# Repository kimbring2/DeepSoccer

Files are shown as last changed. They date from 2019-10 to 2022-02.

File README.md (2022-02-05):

# 1. Introduction
The purpose of this project is to make a soccer robot. For that, Robot Operation System (ROS), Deep Learning, 3D printer and Cad are used together. 

Due to the characteristic of Deep Learning, a large amount of training data is required. Thus, virtual simulation tool of ROS called Gazebo is additionally used. The project uses the one of famous Deep Reinforcement Learning algorithm which uses a human expert data for improving performance.

In order to use the robot algorithm trained in the virtual simulation in the real world, I use a CycleGAN for generating view of simulation world from view of real world. 

Finally, hardware information of robot also will be shared as 3D CAD format to allow other researchers, makers can use this project for their own purpose.

More detailed instruction can be found at my [blog post of DeepSoccer](https://kimbring2.github.io/2020/10/08/deepsoccer.html)

# 2. Prerequisite
This project started from originally [Jetbot](https://www.amazon.com/Waveshare-JetBot-AI-Kit-Accessories/dp/B07V8JL4TF/?th=1). Therefore, the hardware and software are advanced form of Jetbot. It is highly recommended that you first try to run original Jetbot before trying DeepSoccer.

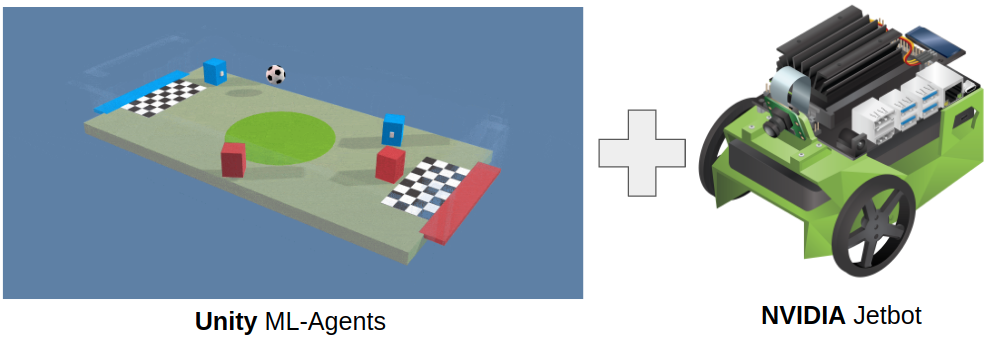
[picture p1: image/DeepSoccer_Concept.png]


# 3. Robot design
I remodel hardware of Jetbot because it is not suitable for soccer. As you know easily, soccer robot needd a kicking and holding part. The Jetbot soccer version can hold a soccer ball and kick it. The wheel part is changed to omniwheel type for moving more freely.

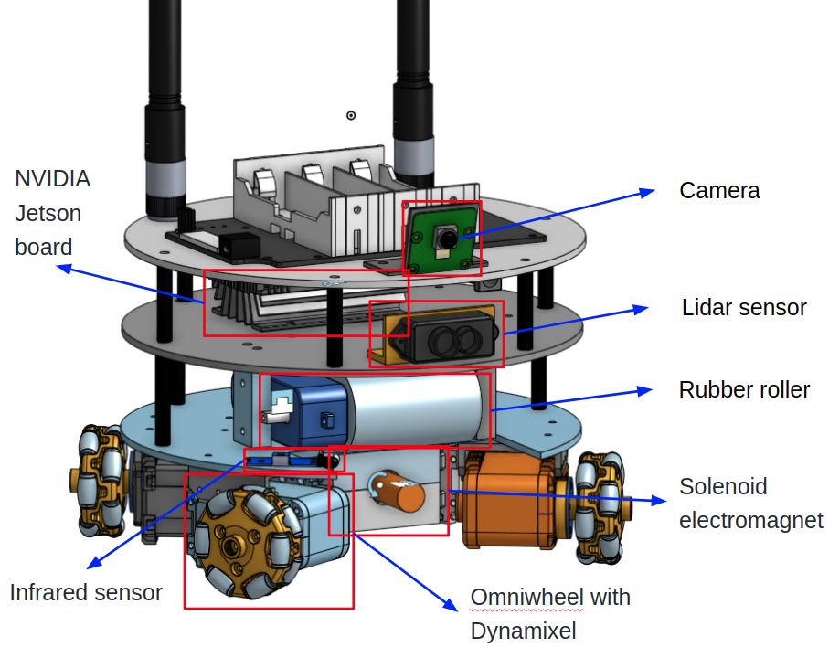
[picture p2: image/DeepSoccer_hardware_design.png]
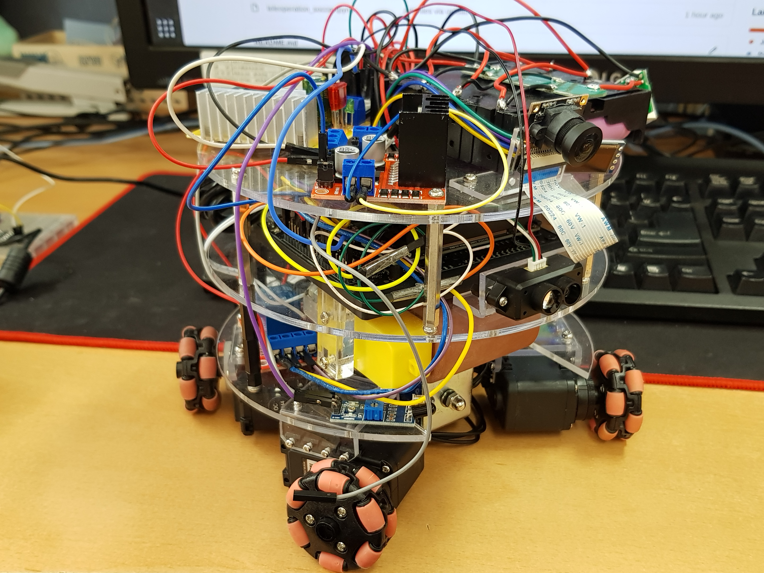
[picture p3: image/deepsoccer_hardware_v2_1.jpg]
 
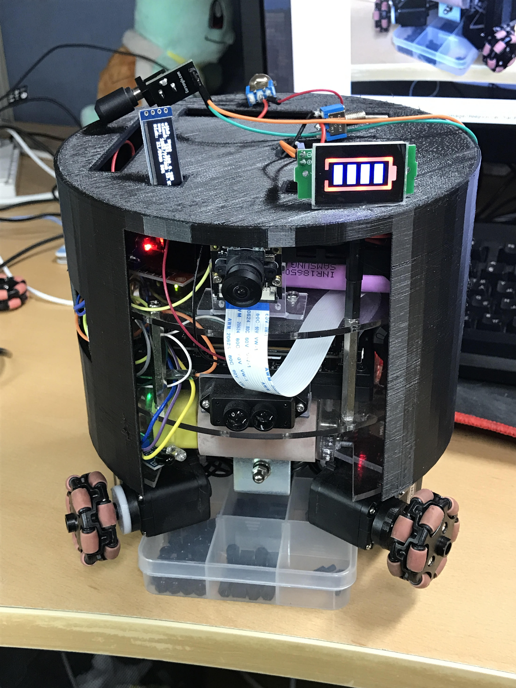
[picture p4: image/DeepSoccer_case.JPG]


You can see detailed information about hardware design at https://kimbring2.github.io/2020/10/08/deepsoccer.html#design_deepsoccer.

# 5. Simulation
## 1. Software Dependency
- ROS Melodic, Gazebo 9
- ROS openai_ros package
- Gazebo only provides Python 2.7(From ROS Noetic at Ubuntu 20.04, Python3 can be used)
- Tensorflow 2.1.0
- requests 
- pynput
- opencv-python

## 2. Network Architecture
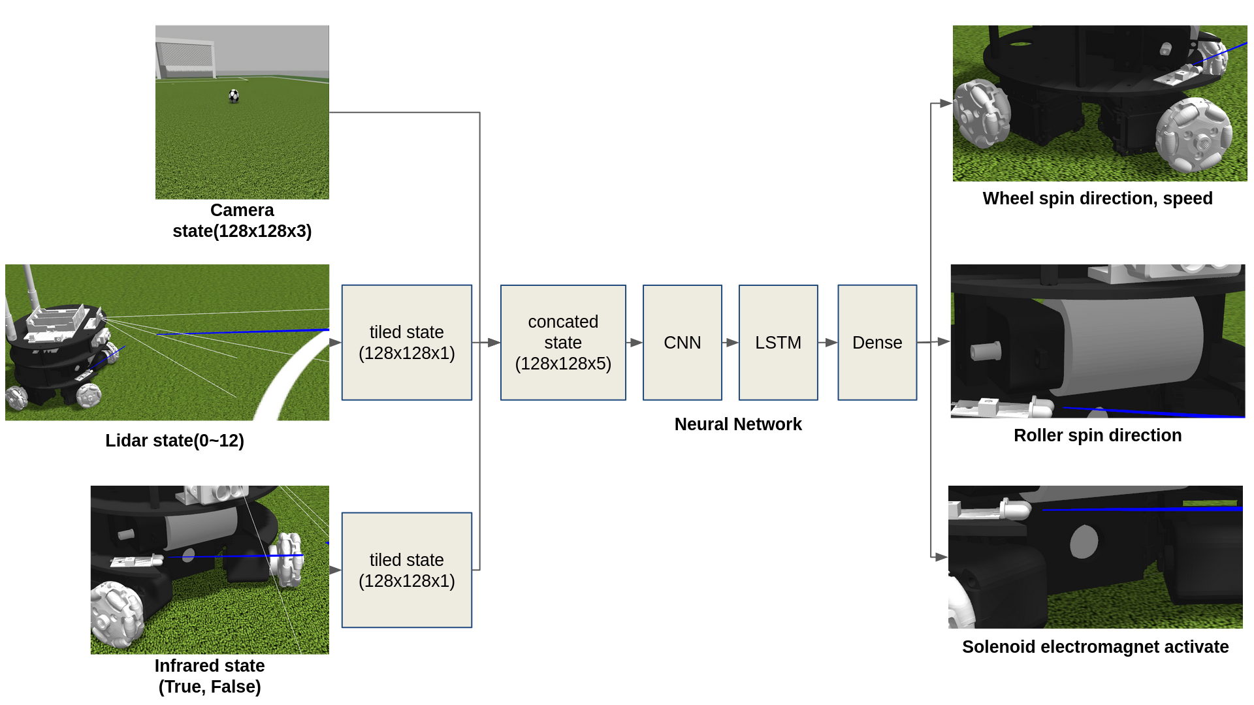
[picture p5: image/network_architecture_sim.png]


## 3. Usage
### ROS package
Please put [deepsoccer_pc](https://github.com/kimbring2/DeepSoccer/tree/master/deepsoccer_pc), [openai_ros](https://github.com/kimbring2/DeepSoccer/tree/master/openai_ros), [openai_ros](https://github.com/kimbring2/DeepSoccer/tree/master/openai_ros), [solenoid_electromagnet_joint_spring_plugin](https://github.com/kimbring2/DeepSoccer/tree/master/solenoid_electromagnet_joint_spring_plugin), [my_deepsoccer_training](https://github.com/kimbring2/DeepSoccer/tree/master/my_deepsoccer_training) folder to your ROS workspace. For example, my path '/home/kimbring2/catkin_ws/src'.

Then, try to run below command to build all ROS package what we put.
```
$ cd ~/catkin_ws/src/
$ git clone https://github.com/kimbring2/DeepSoccer.git
$ cd ..
$ catkin_make
```

If there are no error message, move to next.

### Set model file for soccer field
Copy [deepsoccer_gazebo](https://github.com/kimbring2/DeepSoccer/tree/master/deepsoccer_pc/deepsoccer_gazebo) folder to '/home/[Your User Name]/.gazebo/models' for soccer field rendering.

### Training network using Supervised Learning&Reinforcement Learning
After setting everything mentioned above, download the [human expert data](https://drive.google.com/drive/folders/1QmYI_FL5cym3LTvm8hlLfZ1Bo50bUyfc?usp=sharing) from Google Drive. I collected that data manually. 

After that, extract it to your workspace folder. You need to set a workspace_path in [yaml file](https://github.com/kimbring2/DeepSoccer/blob/master/my_deepsoccer_training/config/deepsoccer_params.yaml).

After preparing the human expert data and config file, run below command. It will start a [tutorial file](https://github.com/kimbring2/DeepSoccer/blob/master/my_deepsoccer_training/src/gym_tutorial.py) of DeepSoccer as format of OpenAI Gym environment. 

```
$ source devel/setup.bash
$ roslaunch my_deepsoccer_training start_tutorial.launch
```

Trained model, Tensorboard log are saved under 'src/train/' folder seperately. Try to check the loss is decreased under 0.3 point. 

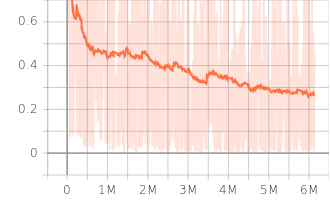
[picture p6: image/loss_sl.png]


If you set the sl_training config to False, pretrained_model to file name of trained model, it will start the Reinforcmenet Learning phase using trained model.

DeepSoccer Supervised Learning demo (https://youtube.com/watch?v=64ENY3P8U88 "DeepSoccer- Click to Watch!")
<strong>Click to Watch!</strong>

### Collection human expert data
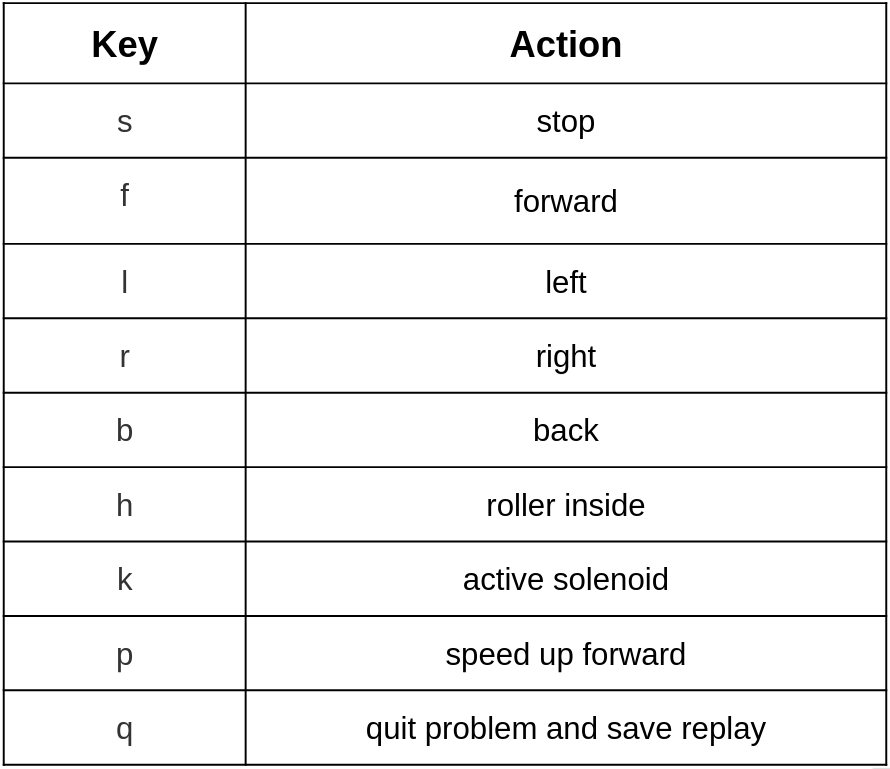
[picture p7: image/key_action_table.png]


You can also collect the human expert dataset using 'roslaunch my_deepsoccer_training start_dataset.launch' command. After Gazebo screen is poped up, you can control robot using 8 command.

The name of the replay file and the path to be saved can be set in the [config file](https://github.com/kimbring2/DeepSoccer/blob/master/my_deepsoccer_training/config/deepsoccer_params.yaml).

## 4. Troubleshooting 
### 1) RLException Error
If you get a 'RLException' error message, use 'source devel/setup.bash' command and try again.

### 2) Could not find the GUI, install the 'joint_state_publisher_gui' package Error
If you get that error when try to run 'roslaunch jetbot_description jetbot_rviz.launch' command, try to install related package using below command at your terminal.

```
$ sudo apt install ros-melodic-joint-state-publisher-gui
```

### 3) Could not load controller Error
If you get a 'Could not load controller' error message, try to install related package using below command at your terminal.

```
$ sudo apt-get install ros-melodic-ros-control ros-melodic-ros-controllers
```

### 4) RViz 'No transform from' error

If you get error message includes 'No transform from', try to install unicode ubuntu package and reboot.

```
$ sudo apt-get install unicode 
```

## 5. Docker 
You can also use a Docker image for this repo using below command. Afte that, you can connect to created container by VNC(http://127.0.0.1:6080/#/).

```
$ docker run -it --rm -p 6080:80 --name=env_1 kimbring2/deepsoccer:latest
```

Because of low speed of Gazebo simulation in Docker image, you need to see Gazebo of it by using host PC. However, you shoud place ROS package to ' /root/catkin_ws/src' for rendering robot model. After that, get IP address of Docker image and connect to it by using below command.

```
$ export GAZEBO_MASTER_IP=$(docker inspect --format '{{ .NetworkSettings.IPAddress }}' env_1)
$ export GAZEBO_MASTER_URI=$GAZEBO_MASTER_IP:11345
$ gzclient --verbose
```

After connecting to the docker image with VNC, move to the catkin_ws folder. Then, you can start the simulation by executing the following command.

# 6. Relationship between simualtion and real part
The purpose of this project is to train Jetbot to play soccer based on simulation and then apply trained model to actual Jetbot. Therefore, I am currently updating the code and description of the current simulation robot and the actual robot to this repository together.

Each ROS package for simulation and real robot is placed separately in two folder.

1. ROS package for simulation robot: https://github.com/kimbring2/DeepSoccer/tree/master/deepsoccer_pc
2. ROS package for real robot: https://github.com/kimbring2/DeepSoccer/tree/master/deepsoccer_jetson
3. Simulation to Real to connect 1, 2 method: https://github.com/kimbring2/DeepSoccer/blob/master/sim2real

You can run each part separately. However, two part should be connected by sim2real method.

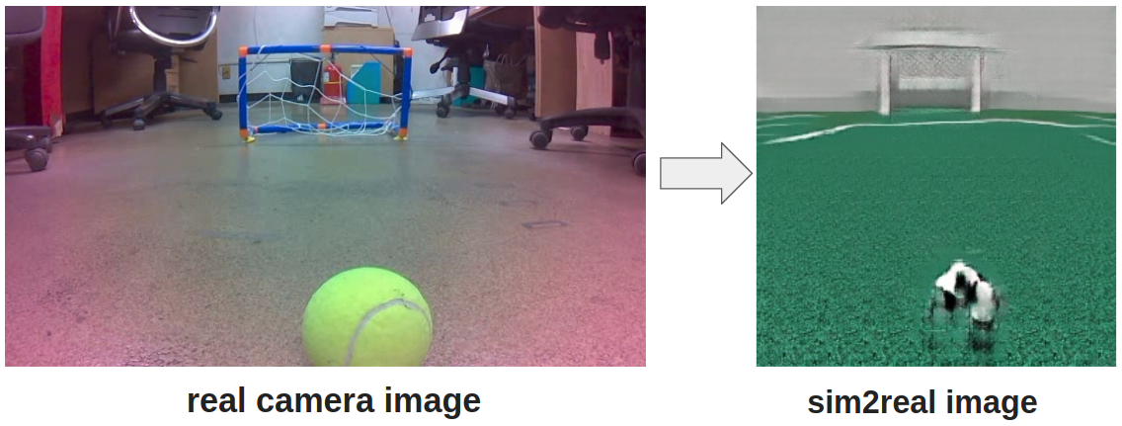
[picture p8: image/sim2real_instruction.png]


# 7. Reference
- Jetbot SDF file, ROS: [Jetbot SDF file, ROS](https://github.com/dusty-nv/jetbot_ros)
- Gazebo parameter setting: [Gazebo parameter](https://github.com/CentroEPiaggio/irobotcreate2ros)
- URDF file usage in Gazebo: [URDF file usage in Gazebo](http://gazebosim.org/tutorials/?tut=ros_urdf)
- Object detecion using cvlib: [Object detecion using cvlib](https://towardsdatascience.com/object-detection-with-less-than-10-lines-of-code-using-python-2d28eebc5b11)
- Soccer field, ball model: [Soccer field, ball model](https://github.com/RoboCup-MSL/MSL-Simulator)
- Reinforcement Learnig model: [Reinforcement Learnig model](https://medium.com/emergent-future/simple-reinforcement-learning-with-tensorflow-part-6-partial-observability-and-deep-recurrent-q-68463e9aeefc)
- Inference saved model: [Tensorrt](http://litaotju.github.io/2019/01/24/Tensorflow-Tutorial-6,-Using-TensorRT-to-speedup-inference/)
- Onshape 3D model to URDF: [onshape-to-robot](https://github.com/rhoban/onshape-to-robot/)
- GPIO control for solenoid electromagnet : https://www.jetsonhacks.com/2019/06/07/jetson-nano-gpio/ ,https://github.com/NVIDIA/jetson-gpio
- Ball kicking mechanism: https://www.youtube.com/watch?v=fVGrYoqn-EU
- How to read LaserScan data(ROS python): https://www.theconstructsim.com/read-laserscan-data/
- Convert Video to Images (Frames) & Images (Frames) to Video using OpenCV (Python) : https://medium.com/@iKhushPatel/convert-video-to-images-images-to-video-using-opencv-python-db27a128a481
- Python Multithreading with pynput.keyboard.listener: https://stackoverflow.com/a/59520236/6152392
- How to use a Gazebo as type of OpenAI Gym: http://wiki.ros.org/openai_ros
- Solenoid joint spring plugin: https://github.com/aminsung/gazebo_joint_torsional_spring_plugin
- Custom control plugin for Gazebo: http://gazebosim.org/tutorials?tut=guided_i5&cat=
- Forgetful Expirience Replay for Reinforcement Learning from Demonstrations: https://github.com/cog-isa/forger
- Compiling ROS cv_bridge with Python3: https://cyaninfinite.com/ros-cv-bridge-with-python-3/
- Style Transfer for Sim2Real: https://github.com/cryu854/FastStyle
- CycleGAN for Sim2Real: https://www.tensorflow.org/tutorials/generative/cyclegan
- Image Segmentation for CycleGAN: https://www.kaggle.com/santhalnr/cityscapes-image-segmentation-pspnet
- Docker Gazebo: https://hub.docker.com/_/gazebo
- Docker image for ROS melodic: https://github.com/fbottarel/docker-ros-desktop-full

# 8. Citation
If you use DeepSoccer to conduct research, we ask that you cite the following paper as a reference:

```
@misc{kim2020deepsoccer,
  author = {Dohyeong, Kim},
  title = {DeepSoccer},
  year = {2020},
  publisher = {GitHub},
  journal = {GitHub repository},
  howpublished = {\url{https://github.com/kimbring2/DeepSoccer/}},
  commit = {9ccab28a7e2a9a14caa119a765f95e2c6d0b044e}
}
```

# 9. Acknowledgement
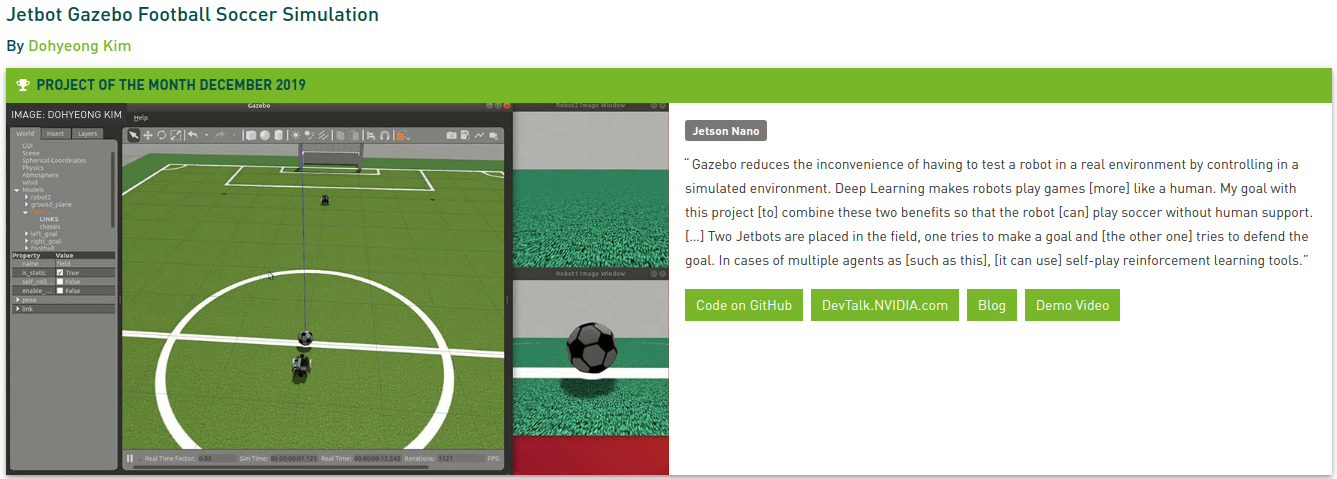
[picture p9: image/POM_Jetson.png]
 <strong>I receive a prize from NVIDIA for this project</strong>

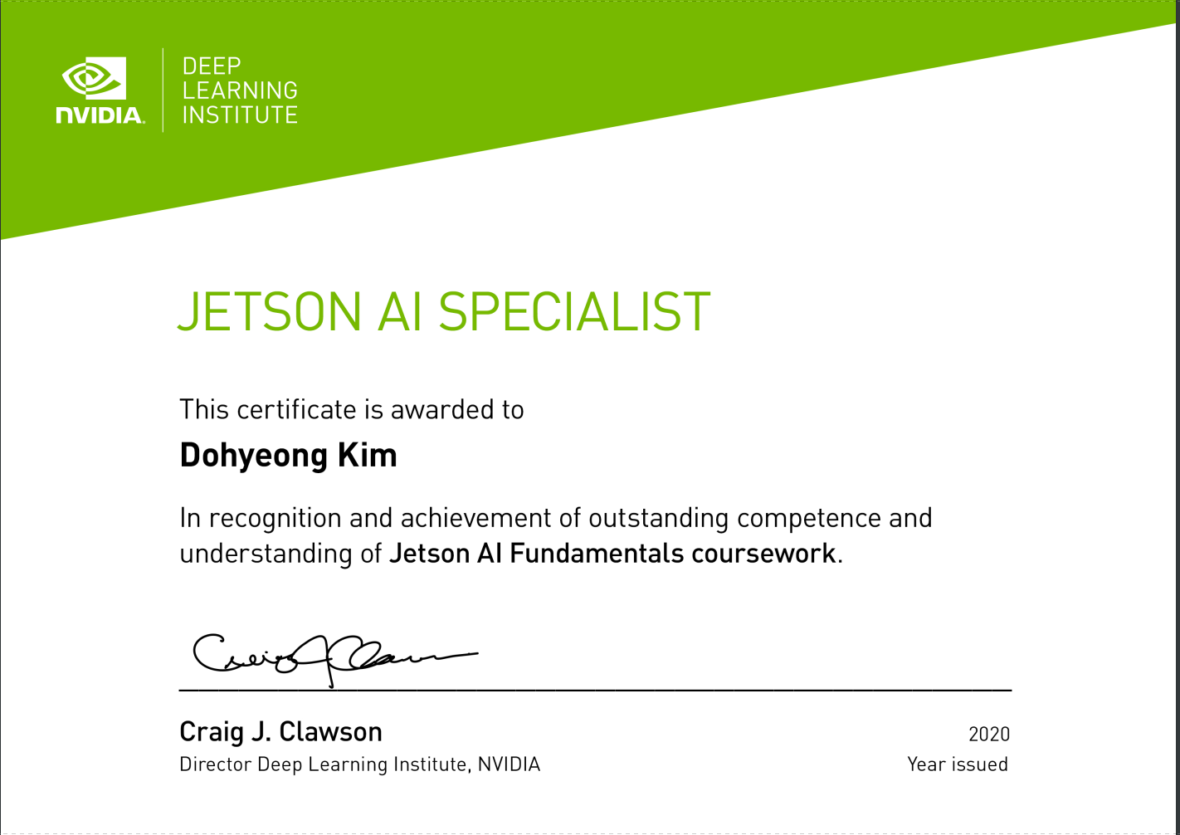
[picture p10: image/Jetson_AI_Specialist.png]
 <strong>I receive Jetson AI Specialist certification from NVIDIA by this project</strong>

# 10. License
Apache License 2.0

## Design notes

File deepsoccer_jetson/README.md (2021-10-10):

# 1. Software Dependency
- JetPack 4.4
- ROS Melodic
- Tensorflow 2.2.0
- Python2 for ROS acuator, sensor node
- Python3 for ROS main node

# 2. Prepare hardware
## Main Board
The main board used in DeepSoccer is Jetson Xavier NX which can run three Deep Learning model at the same time unlike Jetson Nano which can handle only one model one time. However, Jetson Xavier NX is little expensive compared to Jetson Nano. 

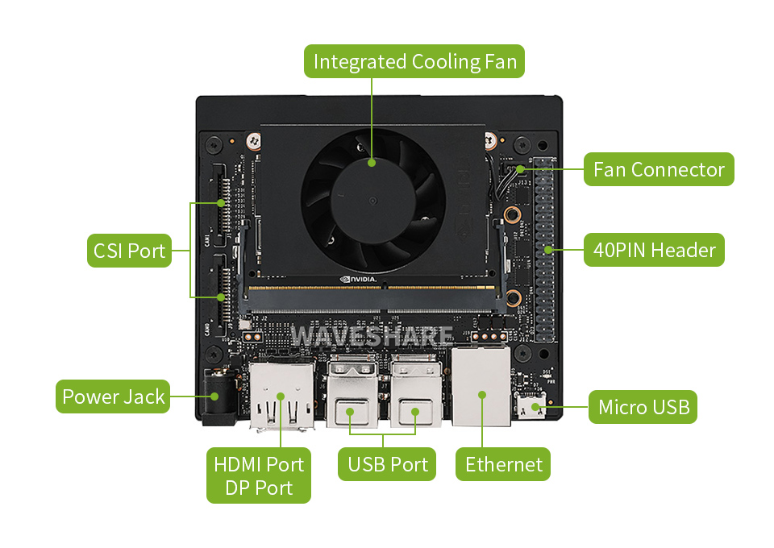
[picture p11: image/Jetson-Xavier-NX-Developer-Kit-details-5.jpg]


This board can run ROS, Python, and Tensorflow. Therefore, you can develop yout own application easily. It is also very convenient to use sensors and actuators as it supports almost all communication interfaces such as I2C, SPI, Digital input / output, CSI and USB.

1. [NVIDIA Jetson Xavier NX](https://www.amazon.com/NVIDIA-Jetson-Xavier-Developer-812674024318/dp/B086874Q5R)

Purchases can generally be made through Amazon. Unlike the Jetson Nano, which can be operated with three 18650 batteries, the Jetson Xavier NX requires four 18650 batteries to operate stably. 

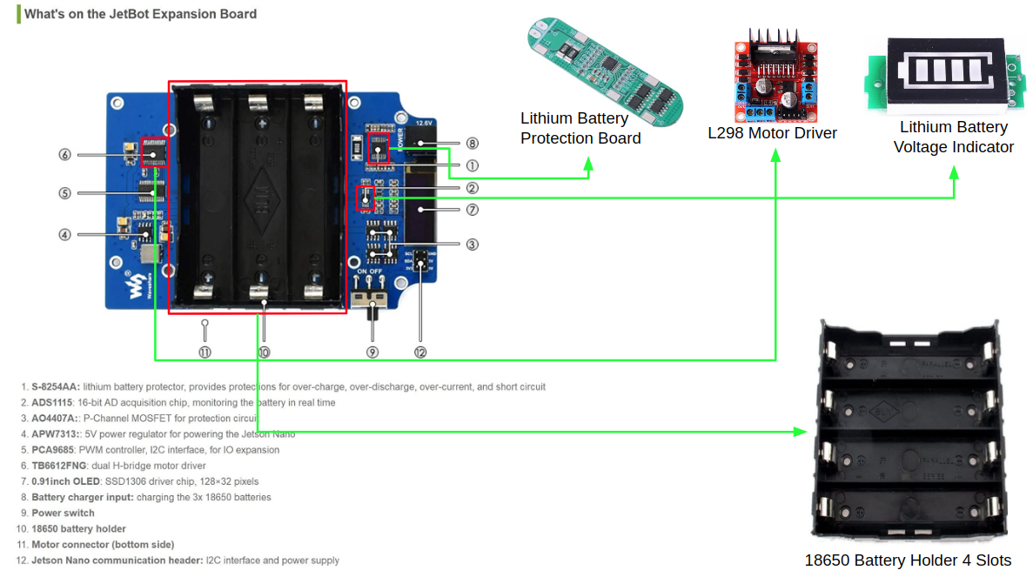
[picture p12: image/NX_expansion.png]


2. [18650 Battery Holder 4 Slots](https://www.amazon.com/abcGoodefg-Battery-Holder-Plastic-Storage/dp/B071XTGBH6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)
3. [Lithium Battery Protection Board](https://www.amazon.com/ZRM-Lithium-Protection-Overcharge-Electronic/dp/B07RGPSSQS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)
4. [Lithium Battery Voltage Indicator](https://www.amazon.com/1S-3-7V-Battery-Voltage-Tester/dp/B01N9M05DA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)
5. [L298 Motor Driver](https://www.amazon.com/HiLetgo-Controller-Stepper-H-Bridge-Mega2560/dp/B07BK1QL5T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)

## OLED
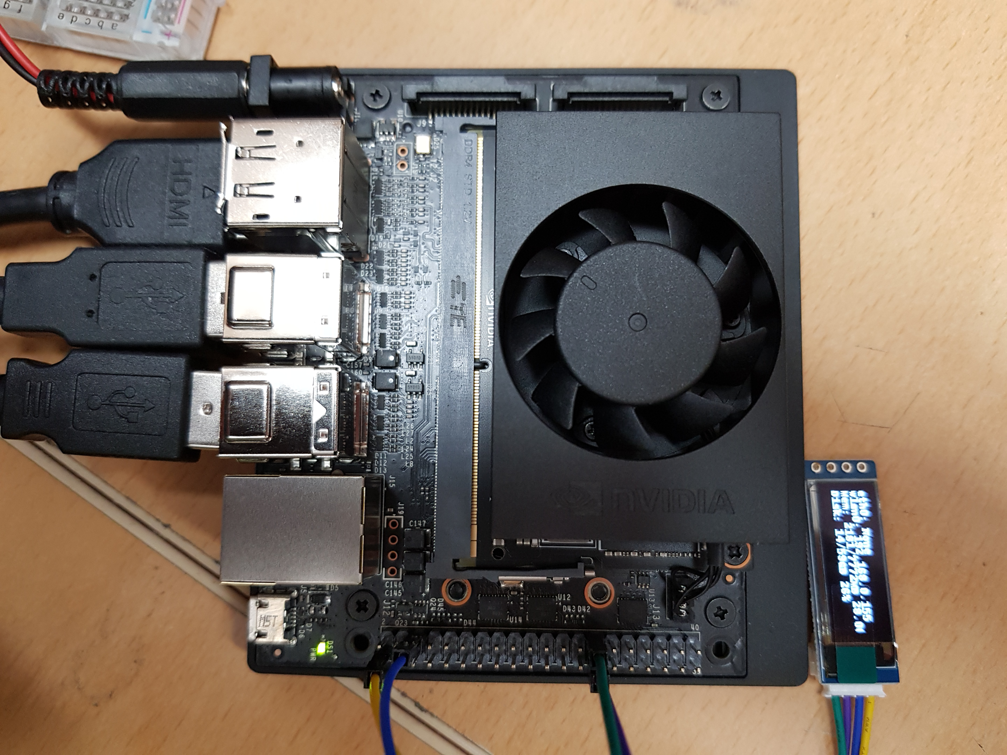
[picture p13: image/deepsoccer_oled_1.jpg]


DeepSoccer has OLED display like an original Jetbot to monitor IP Address, memory usage without monitor connection.

1. [Waveshare OLED module](https://www.waveshare.com/0.91inch-oled-module.htm)

Jetson Xavier NX is connected to OLED module by using VDC, GND and SCL, SDA of 0 Channel I2C.

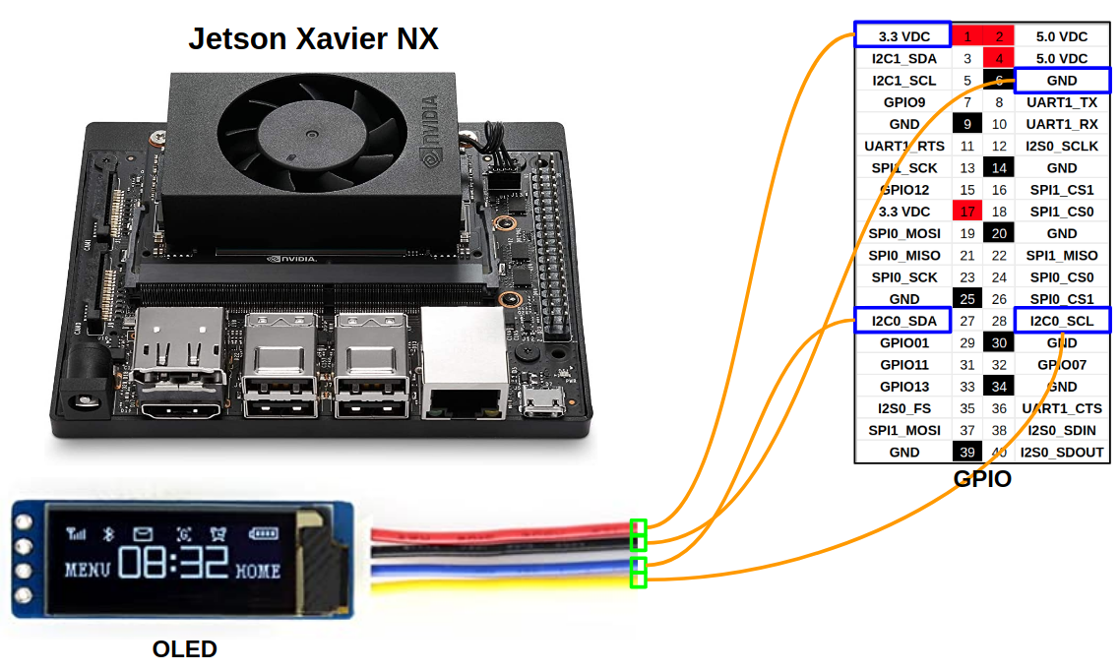
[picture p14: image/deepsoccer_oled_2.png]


After connecting the hardware, download the Jetbot package from https://github.com/NVIDIA-AI-IOT/jetbot to Jetson Xaiver NX and install it using setup.py file. In this package, execute a python file(https://github.com/NVIDIA-AI-IOT/jetbot/blob/master/jetbot/utils/create_stats_service.py) that displays the current information in OLED.

After that, try to register sevice to execute OLED file automatically when the board boot. First, move to /etc/systemd/system/ location of Ubuntu. Then, create a file named deepsoccer_stats.service with following contents.

```
[Unit]
Description=DeepSoccer stats display service
[Service]
Type=simple
User=kimbring2
ExecStart=/bin/sh -c "python3 /home/kimbring2/jetbot/jetbot/apps/stats.py"
Restart=always
[Install]
WantedBy=multi-user.target
```

Then, register the file as a service and start it as shown below.

```
$ systemctl daemon-reload
$ systemctl enable deepsoccer_stats
$ systemctl start deepsoccer_stats
```

The registered service can be confirmed with the following command.

```
sudo systemctl status deepsoccer_stats
```

## Wheel
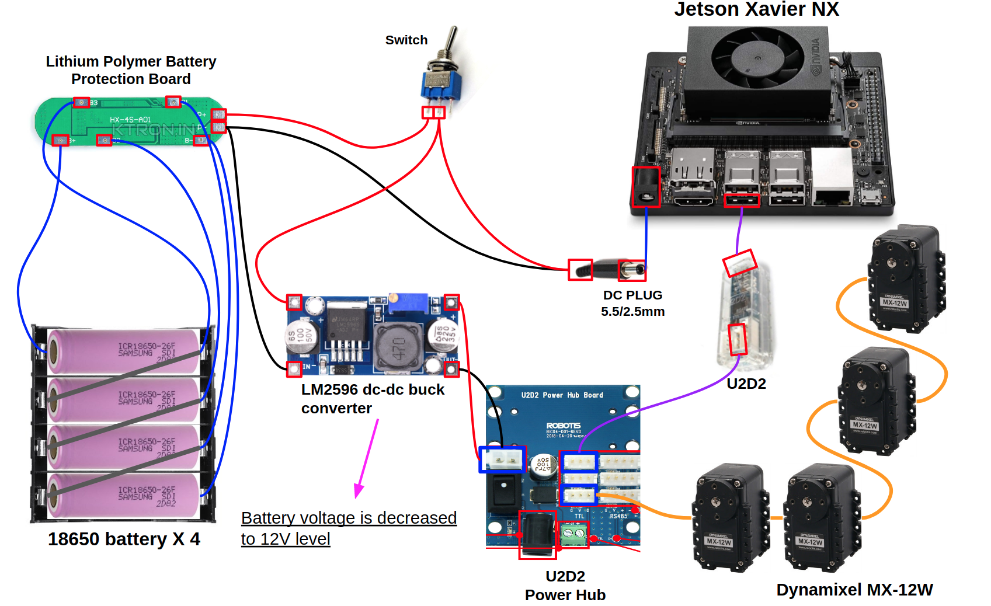
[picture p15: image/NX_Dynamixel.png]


The U2D2 board and U2D2 power hub can be purchased at the Robotis shopping mall. However, if you have existing one, you can change only the 12V power supply method and use the rest as it is.

1. [U2D2](http://www.robotis.us/u2d2/)
2. [U2D2 Power Hub](http://www.robotis.us/u2d2-power-hub-board-set/)
3. [Dynamixel MX-12W](https://www.robotis.us/dynamixel-mx-12w/)
4. [Omniwheel(Korea local shop)](http://robomecha.co.kr/product/detail.html?product_no=10&cate_no=1&display_group=2)
5. [DC-DC buck converter LM2596](https://ko.aliexpress.com/item/33004374185.html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)

ID and communication method and firmware version of of Dynamixel can given via a program provided by ROBOTIS. I test a motor seperately before installing it to robot body. A power supply and TTL communication can be done by using a U2D2 board and power hub.

## Roller
The mechanism for controlling the ball is composed of a rubber roller for fixing and a solenoid electromagnet for kicking.

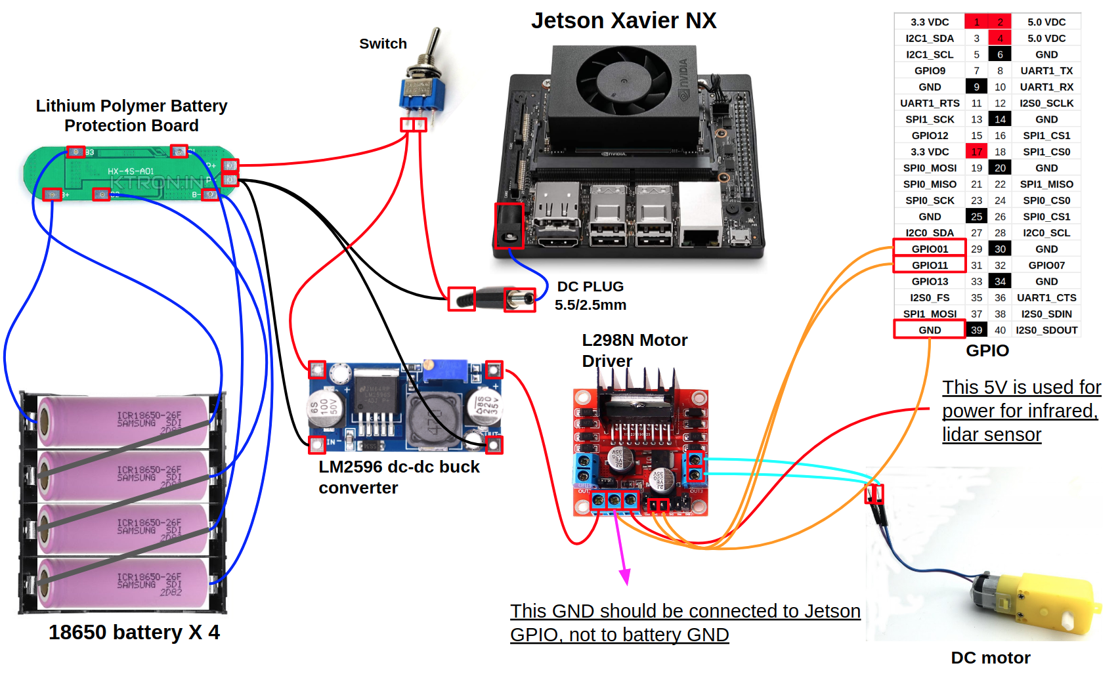
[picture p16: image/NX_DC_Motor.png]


1. [Engraving rubber roller(Made in Korea)](
https://www.ebay.com/itm/50mm-Engraving-Rubber-Roller-Brayer-Stamping-Printing-Screening-Tool-Korea-/153413802463)

For the part for grabiing the soccer ball, I use a part of engraving roller. The core of the roller is made by 3D printer and connected to a DC motor which is included in origin Jetbot.

## Solenoid
For the part for kicking the soccer ball, I use a solenoid electromagnet. To control the solenoid electromagnet in the ROS, we should control GPIO using code. I use a GPIO library of Jetson (https://github.com/NVIDIA/jetson-gpio) provided by NVIDIA.

It is determined that directly connecting the solenoid motor directly to the 12V power supply can not enough force to kick the ball far. Therefore, large capacity capacitor and charging circuit for it is added. Thankfully I could find circuit and component for this at https://drive.google.com/file/d/17twkN9F0Dghrc06b_U9Iviq9Si9rsyOG/view.

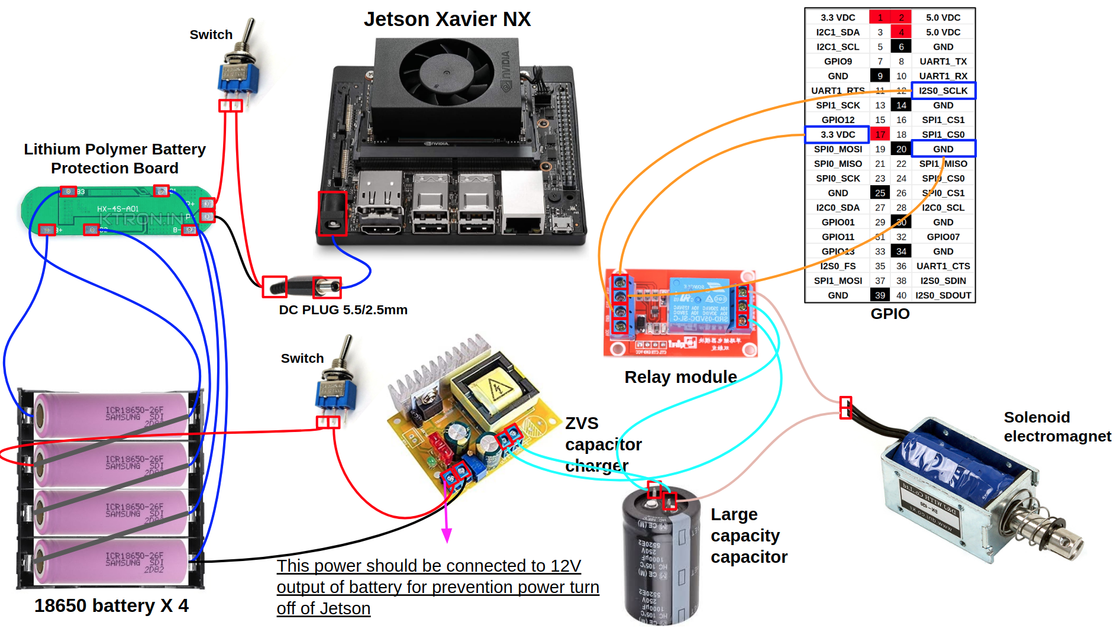
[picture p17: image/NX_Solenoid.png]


1. [Large Capacity Capacitor](https://www.aliexpress.com/item/32866139188.html?spm=a2g0s.9042311.0.0.2db94c4dNsaPDZ)
2. [Large Capacitor Charger](https://www.aliexpress.com/item/32904490215.html?spm=a2g0s.9042311.0.0.27424c4dANjLyy)
3. [Limit switch(Relay module can replace it)](https://www.aliexpress.com/item/32860423798.html?spm=a2g0s.9042311.0.0.2db94c4dNsaPDZ)

After a 250v 1000uf capacitor and a ±45V-390V capacitor charger are added, a solenoid can push a heavy a billiard ball to considerable distance.

## Seosor
In addition to the actuators, the robot must observe the current state to decide which action is best at now. For that, DeepSocce robot is equipped with an infrared sensor to check whether robot is holding a ball using roller front side obstacle to prevent crash.

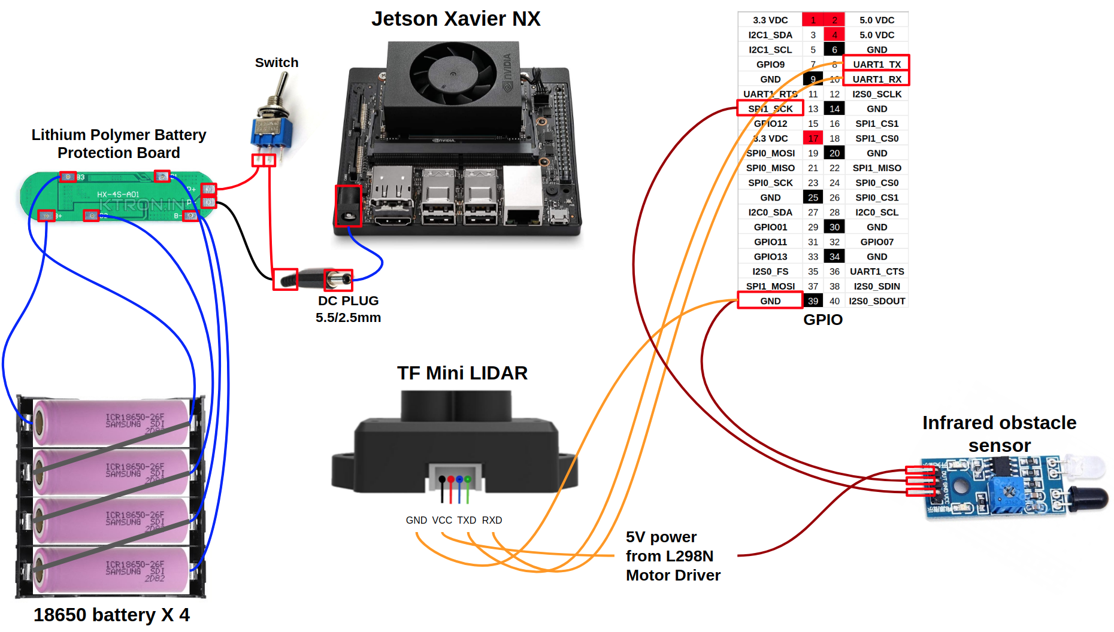
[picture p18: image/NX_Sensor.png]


1. [Infrared Sensor](https://ko.aliexpress.com/item/32391592655.html)
2. [Ridar Sensor](https://www.adafruit.com/product/3978)

The infrared sensor is needed to be connected to the GPIO for digital signals on the Jetson board because it gives 0 and 1 signals. The Lidar sensor which send a signal as UART format is connected to the GPIO of Jetson for UART.

# 3. Usage
First, set up ROS in actual Jetbot hardware based on manual of https://github.com/dusty-nv/jetbot_ros.

Then run roscore on Jetbot terminal and publish the camera frame using jetbot_camera node.
```
$ roscore 
$ rosrun deepsoccer_ros deepsoccer_camera 
```

You can control a wheel motor using below Python script. 
```
$ rosrun deepsoccer_ros deepsoccer_motors.py 
$ rostopic pub -1 /deepsoccer_motors/cmd_str_wheel1 std_msgs/String --once "'30'"
$ rostopic pub -1 /deepsoccer_motors/cmd_str_wheel2 std_msgs/String --once "'30'"
$ rostopic pub -1 /deepsoccer_motors/cmd_str_wheel3 std_msgs/String --once "'30'"
$ rostopic pub -1 /deepsoccer_motors/cmd_str_wheel4 std_msgs/String --once "'30'"
```

You can control a roller and solenoid motor using two Python script. 
```
$ rosrun deepsoccer_ros deepsoccer_roller.py 
$ rostopic pub -1 /deepsoccer_roller/cmd_str std_msgs/String --once "in"
$ rostopic pub -1 /deepsoccer_roller/cmd_str std_msgs/String --once "out"
```

```
$ rosrun deepsoccer_ros deepsoccer_solenoid.py 
$ rostopic pub -1 /deepsoccer_solenoid/cmd_str std_msgs/String --once "in"
$ rostopic pub -1 /deepsoccer_solenoid/cmd_str std_msgs/String --once "out"
```

For getting lidar sensor distance and infrared object detection value.
```
$ sudo chmod a+rw /dev/ttyTHS0
$ rosrun deepsoccer_ros deepsoccer_lidar.py
$ rostopic echo /deepsoccer_lidar
```

```
$ rosrun deepsoccer_ros deepsoccer_infrared.py
$ rostopic echo /deepsoccer_infrared
```

You can start all node by just one command line.

```
$ roslaunch deepsoccer_ros start.launch
```

You can also give a control command using Python code. Run 'jetson_soccer_main.py' file at Jetson Nano terminal.
```$ python deepsoccer_main.py ```

# 4. Teleoperation
Like the original version of Jetbot, DeepSoccer can be controlled by gamepad. You can check a code for that [teleoperation_soccer.ipynb](https://github.com/kimbring2/DeepSoccer/blob/master/etc/teleoperation_soccer.ipynb) file.

## Setting Jupyter Notebook
Upload it to Jetson board and run the Jupyter Notebook. Below command is for setting Jupyter Notebook to use it as remotely.

```
$ pip3 install jupyterlab
$ jupyter notebook --generate-config
```

Next, open ipython and generate a hash to set the password.

```
$ ipython

In [1]: from IPython.lib import passwd

In [2]: passwd()
Enter password: 
Verify password: 
Out[2]: 'sha1:60f3ac9aec93:be2d6048e9b1e7ae0f1ccbad9d746734bf5c3797'
```

Next, record generated hash in the jupyter_notebook_config.json file created at previous step.

```
$ sudo vi ~/.jupyter/jupyter_notebook_config.json

c = get_config()
c.NotebookApp.ip = '0.0.0.0'
c.NotebookApp.open_browser = False
c.NotebookApp.port = 8080
c.NotebookApp.password = 'sha1:60f3ac9aec93:be2d6048e9b1e7ae0f1ccbad9d746734bf5c3797'
```

Finally, start Jupyter Notebook with the password you set.

```
$ jupyter notebook
```

Before that, you need to open port for Dynamixel controller and Lidar sensor via below command.

```
$ sudo chmod a+rw /dev/ttyUSB0
$ sudo chmod a+rw /dev/ttyTHS0
```

## Controlling robot using PS4
The teleoperation Notebook first checks camera, lidar, infrared, wheel works well separetely. After that, it connects them to PS4 controller like a original Jetbot. 

<img src="/image/teleoperation_ps4.png" width="400">

[![DeepSoccer teleoperation test](https://img.youtube.com/vi/vONoIruznlw/hqdefault.jpg)](https://www.youtube.com/watch?v=vONoIruznlw "DeepSoccer Teleoperation - Click to Watch!")
<strong>Click to Watch!</strong>

## Collection real world data 
For Simulation to real conversion, the camera video data when robot plays soccer in the real world is required. You can record the camera image while you are operating the robot via the PS4 controller. Since the original Jetbot do not have a recording function, you need to copy modified [opencv_gst_camera.py] (https://github.com/kimbring2/DeepSoccer/blob/master/etc/opencv_gst_camera.py) file to camera folder of jetbot Python package.

```
import jetbot
print(jetbot.__file__)
/usr/local/lib/python3.6/dist-packages/jetbot-0.4.3-py3.6.egg/jetbot/__init__.py
```

After copying the file, you can use the the record_start and record_stop function. The video file is basically saved under the Desktop folder as content_video.avi name and format.

```
from jetbot import Camera

camera = Camera.instance()

camera.record_start()
camera.record_stop()
```

https://github.com/kimbring2/DeepSoccer/blob/master/image/content_video_sample.mp4

Saved video file can be converted to a image file via the following command to use as the dataset.

$ ffmpeg -i content_video_1.avi -vf fps=30 out%d.png

# 5. Using pretrained model at Jetson board
## Network Architecture
<img src="/image/network_architecture_real.png" width="800">

## Usage
In order to use the model trained by Gazebo simulation at Jetson embedded board. You need to copy a folder named pre_trained_model.ckpt generated after training at previous step. Inside the folder, there are assets and variables folders, and frozen model named saved_model.pb.

After placing [DeepSoccer_ROS Package](https://github.com/kimbring2/DeepSoccer/tree/master/deepsoccer_jetson) to your ROS workspace of Jetson Xavier NX, run below command.

```
$ roscore
$ roslaunch deepsoccer_ros start.launch
```

It will launch all actuator and sensor ROS node. After that, change a pre_trained_model.ckpt folder path what you copied at [deepsoccer_main.py](https://github.com/kimbring2/DeepSoccer/blob/master/deepsoccer_jetson/scripts/deepsoccer_main.py). Next, move to script folder of deepsoccer_ros ROS package and run below command.

```
$ python3 deepsoccer_main.py
```

Because Tensorflow 2 of Jetson Xavier NX only can be run by Python3, you need to do one more job because cv_bridge of ROS melodic is not able to be ran at Python3. Please follow a intruction at https://cyaninfinite.com/ros-cv-bridge-with-python-3/.

If the tasks described on the above site are completed successfully, DeepSoccer start to control acuator based on the data from real sensor.

[![DeepSoccer sim2real test](https://img.youtube.com/vi/Co2rw6-GZbE/sddefault.jpg)](https://www.youtube.com/watch?v=Co2rw6-GZbE "DeepSoccer Sim2Real - Click to Watch!")
<strong>Click to Watch!</strong>

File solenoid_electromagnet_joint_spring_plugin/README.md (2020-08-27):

# Gazebo Solenoid Electromagnet Spring plugin 
This Gazebo/ROS plugin allows you to easily add a solenoid electromagnet spring to your robot in Gazebo.

### Installation
Place this foler to your catkin workspace and use 'catkin_make' command.

### Adding plugin
This plugin attaches to a joint, so the plugin needs to be given a reference to that link.

```
<robot>
  <joint name="stick" type="prismatic">
    <origin xyz="-0.281228 -0.278693 -0.136057" rpy="-5.12956e-06 7.06783e-08 -1.534" />
    <parent link="body_1" />
    <child link="roller_stick_1" />
    <axis xyz="-1 0 0"/>
    <limit lower="-0.02" upper="0.01" effort="30" velocity="30" />
    <joint_properties friction="1.0"/>
  </joint>
    
  <gazebo>
    <plugin name="stick_solenoid_electromagnet_joint_spring" filename="libsolenoid_electromagnet_joint_spring_plugin.so">
      <kx>1000</kx>
      <set_point>0.01</set_point>
      <joint>stick</joint>
    </plugin>
  </gazebo>
</robot>
```

### Parameters

``kx`` : The spring coefficient in N-m

``set_point`` : The pooint at which the solenoid electromagnet joint would feel no force 

``joint`` : Name of the joint to add the solenoid electromagnet to

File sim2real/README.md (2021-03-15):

# Code description
Simulation to Real part consists of two step. The first step is to segment an important part from the real image. 

ADE20K dataset is used to segment image using [ADE20K dataset](https://groups.csail.mit.edu/vision/datasets/ADE20K/). 
Download dataset and move it under your workspace. You need to set that path in [segmentation.ipynb](https://github.com/kimbring2/DeepSoccer/blob/master/sim2real/segmentation.ipynb) file.

You are ready to train Segmentation model. That model will be used to separate floor from image. However, classic OpenCV method 
is used to get ball and goalpost part because they have well-marked color such as green, red.

You can check how to run it together in file. Try to segment [content_image](https://drive.google.com/drive/folders/1TuaYWI191L0lc4EaDm23olSsToEQRHYY?usp=sharing) to. It will be used at next step.

Next step is to convert real image to simulation image using CycleGAN. The dataset for training CycleGAN should become set of image which include goal, goalpost, floor, and wall from various view angle. The reason we applied segmention before this is to remove unrelated object. Please place [segmented content dataset](https://drive.google.com/drive/folders/1S4R7NGOu-IZZskSwGL5YXpU7-fVQLSqR?usp=sharing), [style dataset](https://drive.google.com/drive/folders/166qiiv2Wx0d6-DZBwHiI7Xgg6r_9gmfy?usp=sharing) to your workspace.

You need to set that path in [cyclegan.ipynb](https://github.com/kimbring2/DeepSoccer/blob/master/sim2real/cyclegan.ipynb) file. You are ready to train CycleGAN model. Run each cell of Notebook. 

Trained model will be copied to Jetson board to convery camera image to image of simulation for Sim2Real.

# Software Dependency
- Tensorflow 2.2.0
- opencv-python

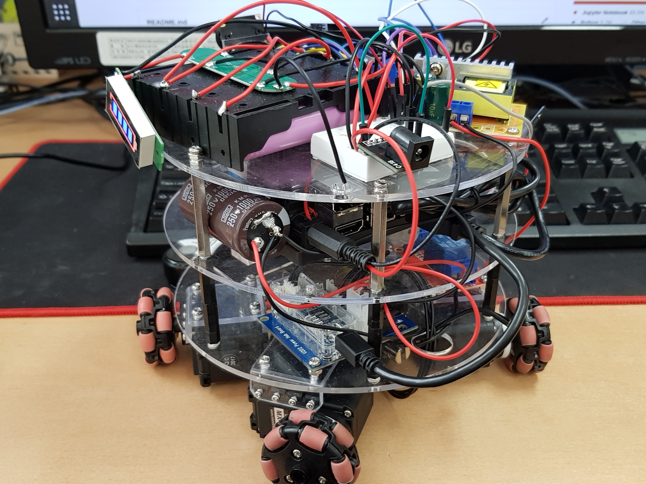
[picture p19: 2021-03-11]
image/deepsoccer_hardware_v2_3.jpg

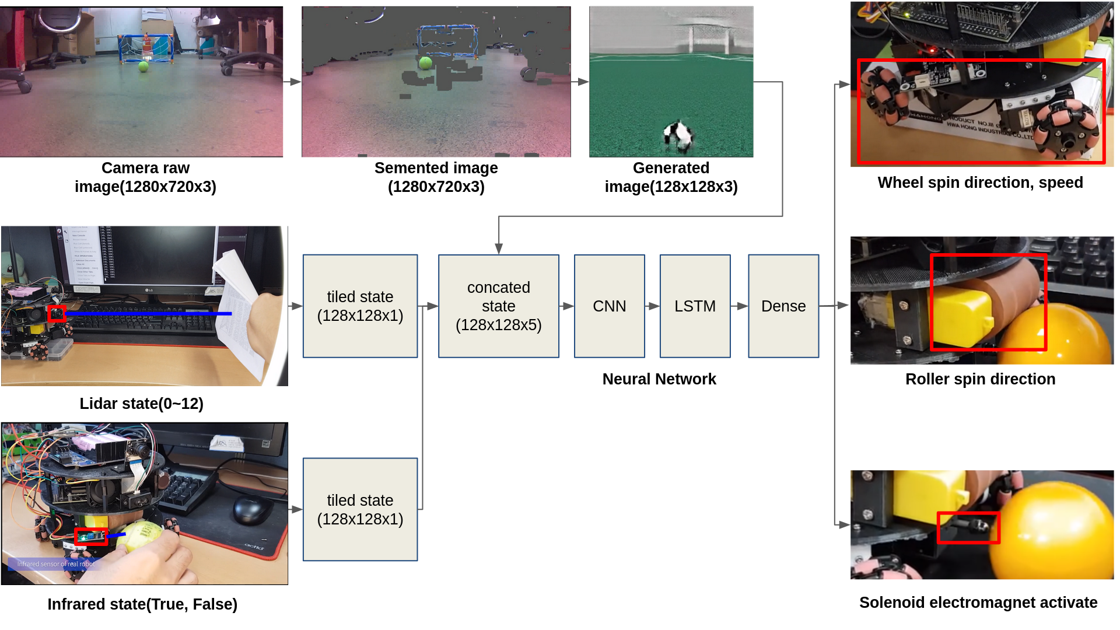
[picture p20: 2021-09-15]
image/network_architecture_real.png

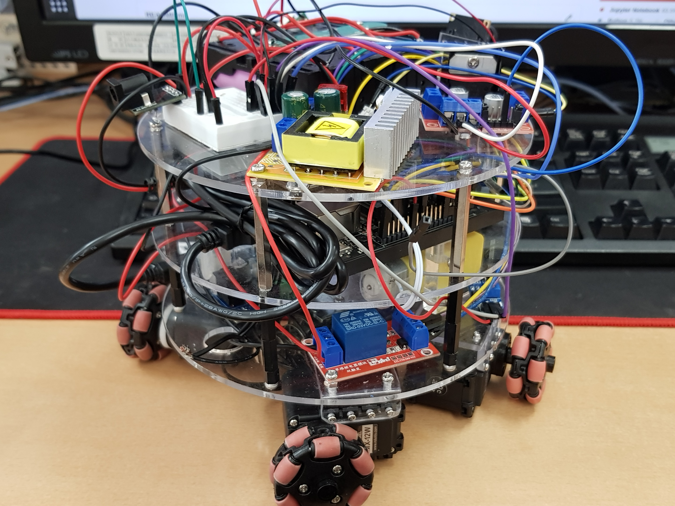
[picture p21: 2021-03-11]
image/deepsoccer_hardware_v2_2.jpg

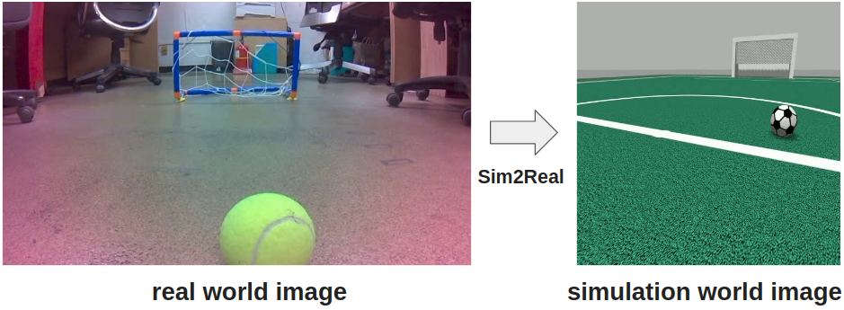
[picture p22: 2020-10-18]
image/sim2real_concept.png

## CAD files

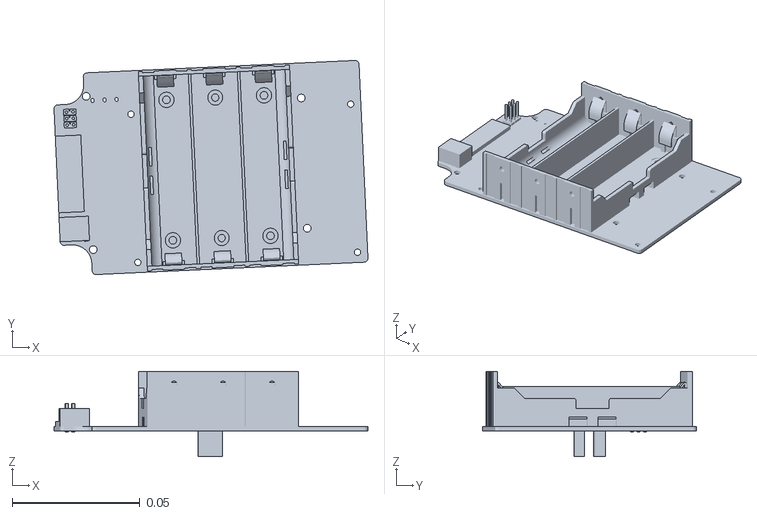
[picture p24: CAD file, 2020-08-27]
deepsoccer_pc/deepsoccer_description/urdf/deepsoccer/jetbot_mainboard_1.stl
0.123 x 0.0837 x 0.0333

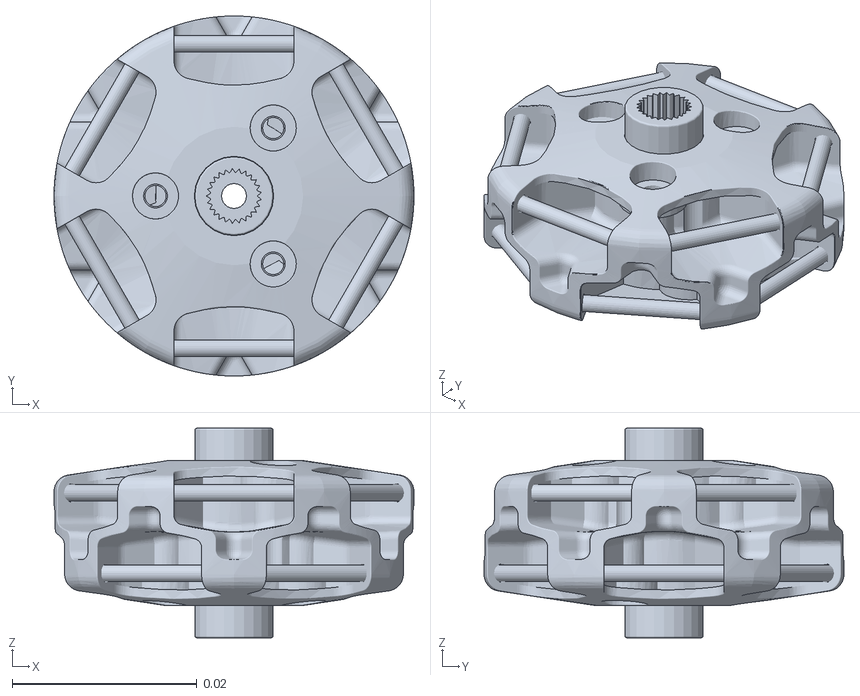
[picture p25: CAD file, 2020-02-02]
deepsoccer_pc/deepsoccer_description/urdf/deepsoccer/main_frame.stl
0.039 x 0.039 x 0.0227

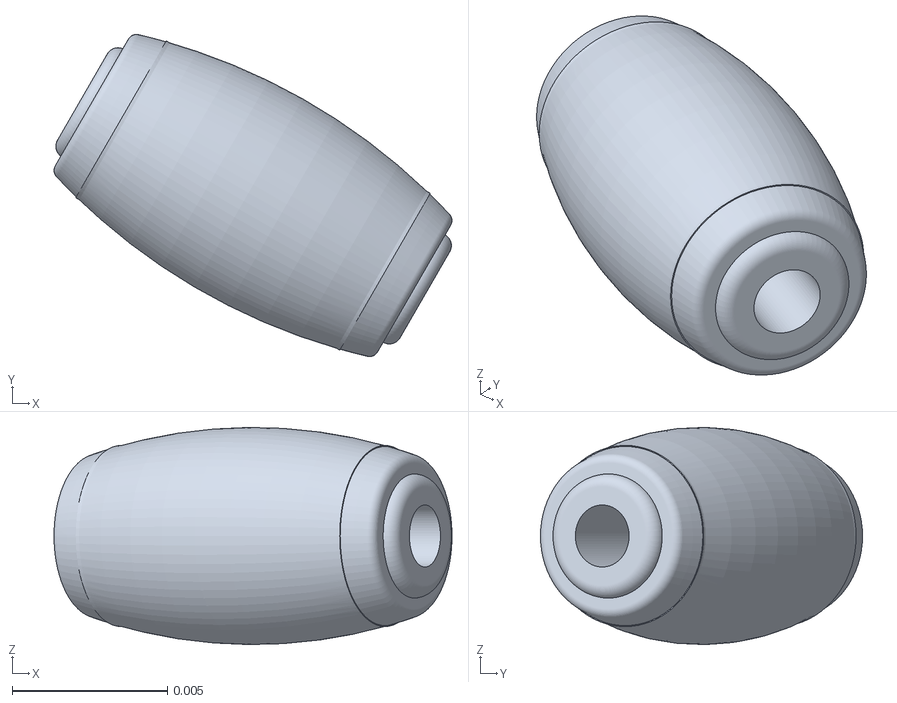
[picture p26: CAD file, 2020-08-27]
deepsoccer_pc/deepsoccer_description/urdf/deepsoccer/wheel1_sub8_1.stl
0.0128 x 0.0104 x 0.007

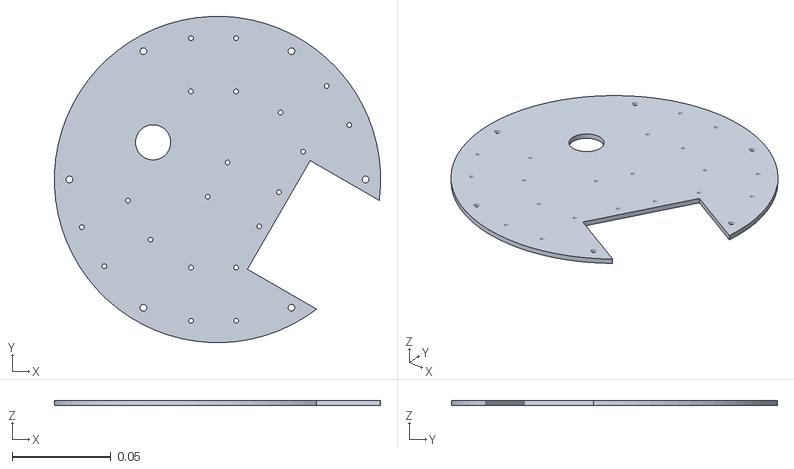
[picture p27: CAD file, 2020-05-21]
jetbot/jetbot_description/urdf/jetbot_soccer/body_1.stl
0.165 x 0.165 x 0.00254

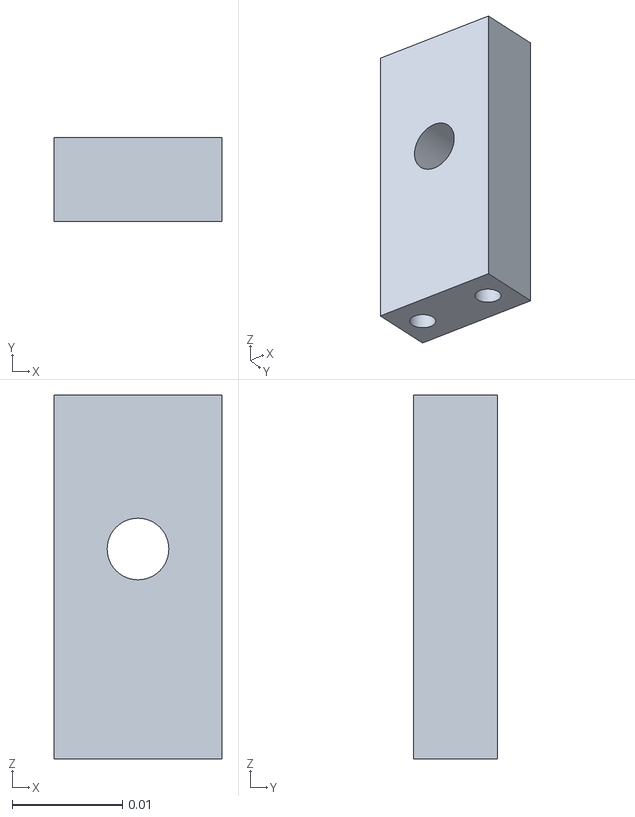
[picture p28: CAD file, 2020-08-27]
deepsoccer_pc/deepsoccer_description/urdf/deepsoccer/part_15.stl
0.0152 x 0.00762 x 0.033

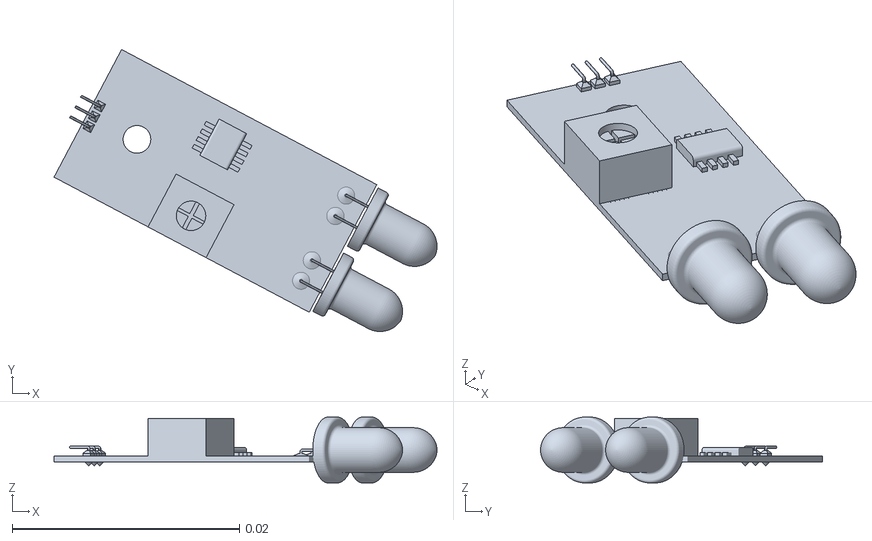
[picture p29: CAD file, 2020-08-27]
deepsoccer_pc/deepsoccer_description/urdf/deepsoccer/ir_sensor_1.stl
0.0337 x 0.0248 x 0.0058

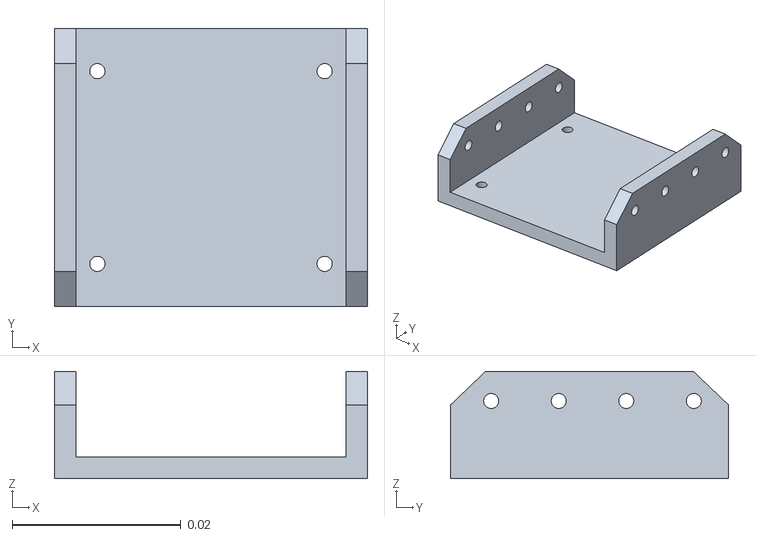
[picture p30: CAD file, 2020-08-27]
deepsoccer_pc/deepsoccer_description/urdf/deepsoccer/suspention.stl
0.0371 x 0.033 x 0.0127

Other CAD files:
deepsoccer_pc/deepsoccer_description/urdf/deepsoccer/wheel2_sub1_1.stl
deepsoccer_pc/deepsoccer_description/urdf/deepsoccer/wheel3_sub7_1.stl
deepsoccer_pc/deepsoccer_description/urdf/deepsoccer/wheel3_sub3_1.stl
deepsoccer_pc/deepsoccer_description/urdf/deepsoccer/wheel2_sub2_1.stl
deepsoccer_pc/deepsoccer_description/urdf/deepsoccer/wheel3_sub4_1.stl
deepsoccer_pc/deepsoccer_description/urdf/deepsoccer/wheel4_sub1_1.stl
deepsoccer_pc/deepsoccer_description/urdf/deepsoccer/wheel4_sub2_1.stl
deepsoccer_pc/deepsoccer_description/urdf/deepsoccer/wheel1_sub1_1.stl
deepsoccer_pc/deepsoccer_description/urdf/deepsoccer/wheel1_sub3_1.stl
deepsoccer_pc/deepsoccer_description/urdf/deepsoccer/wheel2_sub11_1.stl
deepsoccer_pc/deepsoccer_description/urdf/deepsoccer/wheel3_sub9_1.stl
deepsoccer_pc/deepsoccer_description/urdf/deepsoccer/1.14_tft_ips_-_13p_-_reverse_mount.step.stl
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

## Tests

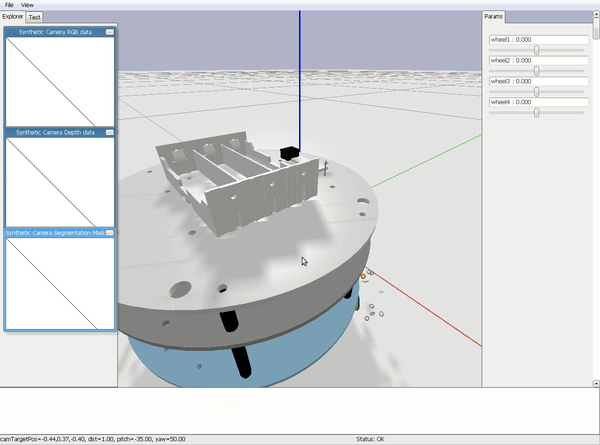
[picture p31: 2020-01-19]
image/Jetbot_Soccer_Pybullet_Test.gif

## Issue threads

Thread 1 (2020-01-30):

RVIZ not showing

xinghuitao, 2020-01-30:
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

Hi,

I run "roslaunch jetbot_description jetbot_rviz.launch" and cannot show the jetbot model in RVIZ. What might be the problems? Thanks!

Regards
Tao

kimbring2, 2020-01-30:
Oh, sorry.

I accidentally touched the file during modification.
To solve that issue, you should add below code in the first part jetbot.xacro file.

`
''''
<xacro:include filename="$(find jetbot_description)/urdf/jetbot.gazebo" />

<!-- Used for fixing robot to Gazebo 'base_link' -->
<link name="world"/>

<joint name="fixed" type="fixed">
  <parent link="world"/>
  <child link="chassis"/>
</joint>

<link name="chassis">
''''
`
Sorry for inconvenience,
From Dohyeong

xinghuitao, 2020-01-30:
Hi, Dohyeong

Thanks a lot!
The jetbot shows up, but the camera is receiving images. I run "rostopic echo /tf | grep -i camera_link", which show nothing.
Can you pls look into it as well?
Thanks, I might have to bother you a lot in the future...:P

Regards
Tao

kimbring2, 2020-01-31:
Welcome, Xinghuitao.

Did you run a 'roslaunch jetbot_gazebo main.launch' before listing rostopic?
RVIZ is not for brocasting rospotic. You should launch a Gazebo instead of it.

Please ask me about project. I will do my best to help.

Sincerely,
Dohyeong Kim

xinghuitao, 2020-01-31:
Hi, Dohyeong

Thanks in advance. What I trying to solve is:

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

Thanks
Xinghui

kimbring2, 2020-01-31:
Hi, Xinghui

Thank you for testing. You are doing right.

The reason I changed my existing jetbot.xacro file is that if I put in a world link, the Jetbot would be abnormally placed on Gazebo. To solve these problems fundamentally, I make separate xacro files for Rviz. Now that the repository has been updated, you can use it.

Sincerely,
From Dohyeong

xinghuitao, 2020-02-02:
Thanks!

Closed 2020-02-02.

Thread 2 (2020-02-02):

Could not load controller

xinghuitao, 2020-02-02:
Hi, Dohyeong

I am making progress step by step. Now I get to the stage below:

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

Anything I missed?

Regards
Xinghui

xinghuitao, 2020-02-02:
BTW, when U install tensorflow and opencv-python/cvlib, R they under python2 or python3 env?

Thanks again!

kimbring2, 2020-02-02:
@xinghuitao Oh, hi.

I am using a python 2. Gazebo simulation supports only version 2.
I am checking a issue of cotronller. Please wait little more!!

Thank you,
From Dohyeong

xinghuitao, 2020-02-02:
After I installed tensorflow and cvlib. "the controller cannot find" error is gone. However, there is another one error showing: "No p gain sepecified for pid".

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

Thanks!
From Xinghui

xinghuitao, 2020-02-02:
I found out the pid error is not actually an error by this link.
https://answers.ros.org/question/293830/what-is-the-fix-for-no-p-gain-specified-for-pid-namespace-gazebo_ros_controlpid_gainsback_right_wheel_joint-ros-melodic/

kimbring2, 2020-02-03:
@xinghuitao Oh, I can also see PID error. But, it dose not effect to program.

xinghuitao, 2020-02-03:
@kimbring2 I repeated the process. This time I installed tensorflow-gpu and cvlib first. The  "the controller cannot find" error showed up again.

xinghuitao, 2020-02-03:
@kimbring2 I manually installed "sudo apt-get install ros-melodic-effort-controllers". Now it shows:
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

kimbring2, 2020-02-03:
@xinghuitao Hmm, is it happened when you run a 'roslaunch jetbot_gazebo main.launch'? That process is not related with python directly. But, installing python package is giving some effect to it.

kimbring2, 2020-02-03:
@xinghuitao Can you try to run that tutorial? http://gazebosim.org/tutorials/?tut=ros_urdf. My code is based on that code. I think it will give some clue about problem.

xinghuitao, 2020-02-03:
Sure.
Yes, I was running "roslaunch jetbot_gazebo main.launch".
I moved this to another topic. The "the controller cannot find" is solved by  "sudo apt-get install ros-melodic-effort-controllers".

Closed 2020-02-03.

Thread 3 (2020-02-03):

Exception thrown while initializing controller

xinghuitao, 2020-02-03:
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

xinghuitao, 2020-02-03:
@kimbring2 can you please check if you got an email from taoxh@hotmail.com to your gmail account?
Thanks a lot!

kimbring2, 2020-02-03:
@xinghuitao Hello, I find a resaon of error message. I did not update a 'jetbot_control.yaml' file on Github. It is totally my fault.

It should be changed to like a below.
`
# Publish all joint states -----------------------------------
joint_state_controller:
  type: joint_state_controller/JointStateController
  publish_rate: 50

# Position Controllers ---------------------------------------
joint1_velocity_controller:
  type: velocity_controllers/JointVelocityController
  joint: left_wheel_hinge
  pid: {p: 100.0, i: 0.01, d: 10.0}
joint2_velocity_controller:
  type: velocity_controllers/JointVelocityController
  joint: right_wheel_hinge
  pid: {p: 100.0, i: 0.01, d: 10.0}
`

I am really sorry for wasting time.

P.S. I check your email. Please wait little more for response! I am really interested in making Autonomous drone.

Sincerely,

xinghuitao, 2020-02-04:
@kimbring2 I updated the yaml, yet the error is still there. Then I followed the link: https://github.com/HumaRobotics/mybot_gazebo_tutorial/issues/4 and changed:
"<hardwareInterface>hardware_interface/VelocityJointInterface</hardwareInterface>"
to
"<hardwareInterface>EffortJointInterface</hardwareInterface>"
in jetbot.xacro file.

Then the error is gone. Can you tell me the differences?
Thanks a lot!
Xinghui Tao

kimbring2, 2020-02-04:
@xinghuitao Can you download whole repository and try run again? I also check it works without error message. We need to use same code. I begin to get confused.

Thank you.

xinghuitao, 2020-02-04:
@kimbring2  Sure
On the readme, it says "git clone https://github.com/kimbring2/jetbot_gazebo.git" or I should download the jetbot_football.git?

xinghuitao, 2020-02-04:
@kimbring2 You are right. The jetbot_soccer.git works!

One minor point: on the "Soccer model path setting" documentation, the jetbot.world file needs to be changed as well.

Thanks!
Xinghui Tao

xinghuitao, 2020-02-04:
I closed this one now. everything works~I can see the training starts. Bravo!

Closed 2020-02-04.

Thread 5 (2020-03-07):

Can I run the virtual environment without Jetson Nano?

xiaoyandong08, 2020-03-07:
Dear author, thanks for your fantastic work and sharing. Did you run the virtual environment in the Jetson Nano? If I do not have a Jason Nano, can I run the virtual environment in my PC?

kimbring2, 2020-03-07:
@xiaoyandong08 Thank you for your attention to my project. Actually, I have no experience about virtual environment of Jetson Nano. Thus, I can not confirm your question.

Thank you,
From Dohyeong

xiaoyandong08, 2020-03-07:
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

I mean that are you running the soccer game in ROS and Gazebo without using Jetson Nano? Now I do not have Jetson Nano, but I want to reproduce your soccer game in ROS and Gazebo. Do I need a Jetson Nano to run the ROS and Gazebo?

kimbring2, 2020-03-07:
Oh, I see.You can run a Gazebo/ROS simualtion of Jetbot without real
hardware. You only need a Desktop.

2020년 3월 7일 (토) 오후 4:47, Yandong Xiao <notifications@github.com>님이 작성:

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

xiaoyandong08, 2020-03-07:
> Oh, I see.You can run a Gazebo/ROS simualtion of Jetbot without real hardware. You only need a Desktop. 2020년 3월 7일 (토) 오후 4:47, Yandong Xiao <notifications@github.com>님이 작성:
> […](#)
> @xiaoyandong08 <https://github.com/xiaoyandong08> Thank you for your attention to my project. Actually, I have no experience about virtual environment of Jetson Nano. Thus, I can not confirm your question. Thank you, From Dohyeong I mean that are you running the soccer game in ROS and Gazebo without using Jetson Nano? Now I do not have Jetson Nano, but I want to reproduce your soccer game in ROS and Gazebo. Do I need a Jetson Nano to run the ROS and Gazebo? — You are receiving this because you commented. Reply to this email directly, view it on GitHub <#5?email_source=notifications&email_token=ACUNIV6NROJJN5LELNRFK3LRGH3XJA5CNFSM4LDNIQT2YY3PNVWWK3TUL52HS4DFVREXG43VMVBW63LNMVXHJKTDN5WW2ZLOORPWSZGOEODSCTY#issuecomment-596058447>, or unsubscribe <https://github.com/notifications/unsubscribe-auth/ACUNIV2BWXCLMCXQKAW463DRGH3XJANCNFSM4LDNIQTQ> .

Thanks for your quick reply. Do you know Jetbot can spin to left by a giving degree?

kimbring2, 2020-03-07:
@xiaoyandong08 Welcome. For that purpose, you need to use a joint_position_controller instead of joint_velocity_controller. But, I am only using a joint_velocity_controller in that project.

xiaoyandong08, 2020-03-15:
Dear Dohyeong, can I use "velocity_publisher = rospy.Publisher('/cmd_vel', Twist, queue_size=5)" to control robot1 and robot2 in your code, if I want to make the robot move with a particular heading?

kimbring2, 2020-03-15:
@xiaoyandong08 Hello, that cide was actually remaining part of previous code. Thus, I have not use it yet.

But, based on http://wiki.ros.org/Robots/TIAGo/Tutorials/motions/cmd_vel. We can also give some heading direction command.

I will try it soon and add a code for it.

Thank you for good feedback,
From Dohyeong

xiaoyandong08, 2020-03-16:
Thanks for your quick response. If I want to Publish the cmd_vel to robot1 and robot2, how can I link this command to those robots, that is, do I need to revise yaml file?

kimbring2, 2020-03-16:
@xiaoyandong08

Welcome, every robot hava different rostopic path such as below example.

`
For robot1 rostopic pub -1 /robot1/joint1_velocity_controller/command std_msgs/Float64 "data: 30"
For robot2 rostopic pub -1 /robot2/joint1_velocity_controller/command std_msgs/Float64 "data: 30"
`

You also need to change a controller name of 'robots.launch' in jetbot_gazebo folder and  'jetbot_control.yaml' file in jetbot_control folder.

Thank you.

kimbring2, 2020-03-26:
I close the issue. If you have another question, please make new issue!

Thank you.

Closed 2020-03-26.

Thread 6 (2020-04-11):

Calculate yaw angle form velocity change

Tao-wecorp, 2020-04-11:
Hi, @kimbring2

When we apply left_action or right_action = [40, -40], how can we calculate the yaw angle?

Thanks
Tao

kimbring2, 2020-04-11:
@Tao-wecorp Hi, Tao. Thank you for good question. You can check a position and orientation of robot using '/gazebo/model_states' msg. I think yaw angle is y value of orientation of msg.pose of each robot.

I add a some sample code for it.

`
sub_state = rospy.Subscriber('/gazebo/model_states', ModelStates, state_callback)

def state_callback(msg):
    global state_j
    global d
    robot1_index = (msg.name).index("robot1")
    robot1_pose = (msg.pose)[robot1_index]
    print("robot1_pose.: " + str(robot1_pose))

while not rospy.is_shutdown():
    robot1_action = robot_action_list[2]
    #print("robot1_action: " + str(robot1_action))

    pub_vel_left_1.publish(robot1_action[0])
    pub_vel_right_1.publish(robot1_action[1])
`

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

I wish you are safe from Virus.

Thank you,
From Dohyeong

Tao-wecorp, 2020-04-11:
@kimbring2 Thanks a lot! you keep safe too~

Closed 2020-04-11.

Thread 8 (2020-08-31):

I have tried "python main.py", and installed TensorFlow via "pip install tessorflow", but it was reported like this: "ERROR: No matching distribution found for tensorflow"

cheoljason, 2020-08-31:
Error Message Following
~/catkin_ws/src/DeepSoccer/jetbot/jetbot_control/src$
$ python main.py
Traceback (most recent call last):
  File "main.py", line 16, in <module>
    import cvlib as cv
  File "/home/jetbot/.local/lib/python2.7/site-packages/cvlib/__init__.py", line 8, in <module>
    from .gender_detection import detect_gender
  File "/home/jetbot/.local/lib/python2.7/site-packages/cvlib/gender_detection.py", line 4, in <module>
    from keras.utils import get_file
  File "/home/jetbot/.local/lib/python2.7/site-packages/keras/__init__.py", line 6, in <module>
    'Keras requires TensorFlow 2.2 or higher. '
ImportError: Keras requires TensorFlow 2.2 or higher. Install TensorFlow via `pip install tensorflow`

kimbring2, 2020-08-31:
@cheoljason

Hello, cvlib requires a Tensorflow. You need to install it using 'pip install tensorflow'.

Thank you.

cheoljason, 2020-08-31:
Thanks for answering. Though I have already i tried to install it using 'pip install tensorflow', it didn't work. What should I do to install tensorflow for Python2.7?

kimbring2, 2020-08-31:
@cheoljason Oh, let's try 'pip2 install tensorflow'. You may need to check which python version is related with the pip. Sometimes, there are many environment option for Python.

cheoljason, 2020-08-31:
I installed tensorflow today on the JetBot Python2.7 development environment.
I downloaded tensorflow_gpu-1.13.0rc0+nv19.2-cp27-cp27mu-linux_aarch64.whl from nvidia URL (https://developer.nvidia.com/embedded/downloads#?search=tensorflow) and barely installed tensorflow
The statement is as follows:
$ pip install tensorflow_gpu-1.13.0rc0+nv19.2-cp27-cp27mu-linux_aarch64.whl
$ pip install keras==2.3.1
$ pip install tensorflow-estimator==1.13.0
Nvidia does not currently provide python2.7 tensorflow, so it seems to have been installed complicatedly.

Thank you for opening and supporting kimbrings2's development materials for robot soccer.

Closed 2020-08-31.

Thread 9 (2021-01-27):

CMake Error about gazebo_ros

kjwoo31, 2021-01-27:
I have a problem with building the ROS project. I get an error message as below when I execute 'catkin_make'.
 I did it right after checking jetbot_ros in https://github.com/dusty-nv/jetbot_ros works well.
 I tried downloading gazebo-ros to fix this, but it didn't work. How can I solve this problem?

## error message
-- +++ processing catkin package: 'solenoid_electromagnet_joint_spring_plugin'
-- ==> add_subdirectory(DeepSoccer/solenoid_electromagnet_joint_spring_plugin)
-- Could NOT find gazebo_ros (missing: gazebo_ros_DIR)
-- Could not find the required component 'gazebo_ros'. The following CMake error indicates that you either need to install the package with the same name or change your environment so that it can be found.
CMake Error at /opt/ros/melodic/share/catkin/cmake/catkinConfig.cmake:83 (find_package):
  Could not find a package configuration file provided by "gazebo_ros" with
  any of the following names:

    gazebo_rosConfig.cmake
    gazebo_ros-config.cmake

  Add the installation prefix of "gazebo_ros" to CMAKE_PREFIX_PATH or set
  "gazebo_ros_DIR" to a directory containing one of the above files.  If
  "gazebo_ros" provides a separate development package or SDK, be sure it has
  been installed.
Call Stack (most recent call first):
  DeepSoccer/solenoid_electromagnet_joint_spring_plugin/CMakeLists.txt:5 (find_package)

-- Configuring incomplete, errors occurred!
See also "/home/jetbot/workspace/catkin_ws/build/CMakeFiles/CMakeOutput.log".
See also "/home/jetbot/workspace/catkin_ws/build/CMakeFiles/CMakeError.log".
Makefile:852: recipe for target 'cmake_check_build_system' failed
make: *** [cmake_check_build_system] Error 1
Invoking "make cmake_check_build_system" failed

kjwoo31, 2021-02-04:
Solved by

> sudo apt install ros-melodic-gazebo_ros

kimbring2, 2021-02-04:
Hello,

The 'solenoid_electromagnet_joint_spring_plugin' package is for Gazebo simulation in Desktop.

You need to use the 'https://github.com/kimbring2/DeepSoccer/tree/master/deepsoccer_ros' folder for your Jetson board.

Sorry for the confusion.

Closed 2021-02-04.

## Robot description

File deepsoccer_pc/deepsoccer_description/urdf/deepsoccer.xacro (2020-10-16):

<?xml version="1.0"?>
<robot name="deepsoccer" xmlns:xacro="http://www.ros.org/wiki/xacro">
	<xacro:include filename="$(find deepsoccer_description)/urdf/deepsoccer.gazebo" />

	<link name="body_1">
		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
		<inertial>
			<origin xyz="-0.000875129 0.00232211 -0.116828" rpy="0 0 0"/>
			<mass value="0.793815" />
			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
		</inertial>
	</link>
	<link name="roller_1">
		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
		<inertial>
			<origin xyz="-0.0348369 -8.01773e-05 -1.82817e-17" rpy="0 0 0"/>
			<mass value="0.0499297" />
			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
		</inertial>
	</link>
	<joint name="roller" type="revolute">
		<origin xyz="-0.0347647 -0.0426942 -0.0981546" rpy="-3.14056 -9.70802e-08 -3.11644" />
		<parent link="body_1" />
		<child link="roller_1" />
		<axis xyz="-1 0 0"/>
		<limit lower="-1e+16" upper="1e+16" effort="1.5" velocity="200" />
		<joint_properties friction="0.0"/>
	</joint>
	<link name="horn4_1">
		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
		<inertial>
			<origin xyz="-9.44942e-07 -1.4867e-07 0.012158" rpy="0 0 0"/>
			<mass value="0.00125567" />
			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
		</inertial>
	</link>
	<link name="wheel2_sub2_1">
		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
		<inertial>
			<origin xyz="3.67355e-05 -2.09868e-05 5.31199e-07" rpy="0 0 0"/>
			<mass value="9.9564e-05" />
			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
		</inertial>
	</link>
	<joint name="wheel2_sub1" type="revolute">
		<origin xyz="-0.00825 0.0142894 0.0189056" rpy="3.13998 -0.000933133 -3.14159" />
		<parent link="horn4_1" />
		<child link="wheel2_sub2_1" />
		<axis xyz="-0.866025 0.5 0"/>
		<limit lower="-1e+16" upper="1e+16" effort="1.5" velocity="50" />
		<joint_properties friction="0.0"/>
	</joint>
	<link name="wheel2_sub7_1">
		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
		<inertial>
			<origin xyz="3.67355e-05 -2.09868e-05 5.31199e-07" rpy="0 0 0"/>
			<mass value="9.9564e-05" />
			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
		</inertial>
	</link>
	<joint name="wheel2_sub2" type="revolute">
		<origin xyz="0.00825 0.0142894 0.0189056" rpy="0.00183987 -0.00106225 -9.77202e-07" />
		<parent link="horn4_1" />
		<child link="wheel2_sub7_1" />
		<axis xyz="-0.866025 0.5 0"/>
		<limit lower="-1e+16" upper="1e+16" effort="1.5" velocity="50" />
		<joint_properties friction="0.0"/>
	</joint>
	<link name="wheel2_sub3_1">
		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
		<inertial>
			<origin xyz="3.67355e-05 -2.09868e-05 5.31199e-07" rpy="0 0 0"/>
			<mass value="9.9564e-05" />
			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
		</inertial>
	</link>
	<joint name="wheel2_sub3" type="revolute">
		<origin xyz="0.0165 1.11022e-16 0.0189056" rpy="1.57117 -0.523599 -1.57099" />
		<parent link="horn4_1" />
		<child link="wheel2_sub3_1" />
		<axis xyz="-0.866025 0.5 0"/>
		<limit lower="-1e+16" upper="1e+16" effort="1.5" velocity="50" />
		<joint_properties friction="0.0"/>
	</joint>
	<link name="wheel2_sub9_1">
		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
		<inertial>
			<origin xyz="3.67355e-05 -2.09868e-05 5.31199e-07" rpy="0 0 0"/>
			<mass value="9.9564e-05" />
			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
		</inertial>
	</link>
	<joint name="wheel2_sub4" type="revolute">
		<origin xyz="0.00825 -0.0142894 0.0189056" rpy="3.13998 -0.000933133 -3.14159" />
		<parent link="horn4_1" />
		<child link="wheel2_sub9_1" />
		<axis xyz="-0.866025 0.5 0"/>
		<limit lower="-1e+16" upper="1e+16" effort="1.5" velocity="50" />
		<joint_properties friction="0.0"/>
	</joint>
	<link name="wheel2_sub5_1">
		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
		<inertial>
			<origin xyz="3.67355e-05 -2.09868e-05 5.31199e-07" rpy="0 0 0"/>
			<mass value="9.9564e-05" />
			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
		</inertial>
	</link>
	<joint name="wheel2_sub5" type="revolute">
		<origin xyz="-0.00825 -0.0142894 0.0189056" rpy="0.00183987 -0.00106225 -9.77199e-07" />
		<parent link="horn4_1" />
		<child link="wheel2_sub5_1" />
		<axis xyz="-0.866025 0.5 0"/>
		<limit lower="-1e+16" upper="1e+16" effort="1.5" velocity="50" />
		<joint_properties friction="0.0"/>
	</joint>
	<link name="wheel2_sub4_1">
		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
		<inertial>
			<origin xyz="3.67355e-05 -2.09868e-05 5.31199e-07" rpy="0 0 0"/>
			<mass value="9.9564e-05" />
			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
		</inertial>
	</link>
	<joint name="wheel2_sub6" type="revolute">
		<origin xyz="-0.0165 -5.55112e-17 0.0189056" rpy="1.57117 -0.523599 -1.57099" />
		<parent link="horn4_1" />
		<child link="wheel2_sub4_1" />
		<axis xyz="-0.866025 0.5 0"/>
		<limit lower="-1e+16" upper="1e+16" effort="1.5" velocity="50" />
		<joint_properties friction="0.0"/>
	</joint>
	<link name="wheel2_sub1_1">
		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
		<inertial>
			<origin xyz="3.67355e-05 -2.09868e-05 5.31199e-07" rpy="0 0 0"/>
			<mass value="9.9564e-05" />
			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
		</inertial>
	</link>
	<joint name="wheel2_sub7" type="revolute">
		<origin xyz="2.77556e-16 -0.0165 0.0102056" rpy="3.13965 -0.00112434 2.61799" />
		<parent link="horn4_1" />
		<child link="wheel2_sub1_1" />
		<axis xyz="-0.866025 0.5 0"/>
		<limit lower="-1e+16" upper="1e+16" effort="1.5" velocity="50" />
		<joint_properties friction="0.0"/>
	</joint>
	<link name="wheel2_sub8_1">
		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
		<inertial>
			<origin xyz="3.67355e-05 -2.09868e-05 5.31199e-07" rpy="0 0 0"/>
			<mass value="9.9564e-05" />
			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
		</inertial>
	</link>
	<joint name="wheel2_sub8" type="revolute">
		<origin xyz="0.0142894 -0.00825 0.0102056" rpy="1.56971 -0.523599 -2.09385" />
		<parent link="horn4_1" />
		<child link="wheel2_sub8_1" />
		<axis xyz="-0.866025 0.5 0"/>
		<limit lower="-1e+16" upper="1e+16" effort="1.5" velocity="50" />
		<joint_properties friction="0.0"/>
	</joint>
	<link name="wheel2_sub10_1">
		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
		<inertial>
			<origin xyz="3.67355e-05 -2.09868e-05 5.31199e-07" rpy="0 0 0"/>
			<mass value="9.9564e-05" />
			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
		</inertial>
	</link>
	<joint name="wheel2_sub9" type="revolute">
		<origin xyz="0.0142894 0.00825 0.0102056" rpy="1.5725 -0.523598 -1.04805" />
		<parent link="horn4_1" />
		<child link="wheel2_sub10_1" />
		<axis xyz="-0.866025 0.5 0"/>
		<limit lower="-1e+16" upper="1e+16" effort="1.5" velocity="50" />
		<joint_properties friction="0.0"/>
	</joint>
	<link name="wheel2_sub12_1">
		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
		<inertial>
			<origin xyz="3.67355e-05 -2.09868e-05 5.31199e-07" rpy="0 0 0"/>
			<mass value="9.9564e-05" />
			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
		</inertial>
	</link>
	<joint name="wheel2_sub10" type="revolute">
		<origin xyz="-0.0142894 0.00825 0.0102056" rpy="1.56971 -0.523599 -2.09385" />
		<parent link="horn4_1" />
		<child link="wheel2_sub12_1" />
		<axis xyz="-0.866025 0.5 0"/>
		<limit lower="-1e+16" upper="1e+16" effort="1.5" velocity="50" />
		<joint_properties friction="0.0"/>
	</joint>
	<link name="wheel2_sub6_1">
		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
		<inertial>
			<origin xyz="3.67355e-05 -2.09868e-05 5.31199e-07" rpy="0 0 0"/>
			<mass value="9.9564e-05" />
			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
		</inertial>
	</link>
	<joint name="wheel2_sub11" type="revolute">
		<origin xyz="-0.0142894 -0.00825 0.0102056" rpy="1.5725 -0.523598 -1.04805" />
		<parent link="horn4_1" />
		<child link="wheel2_sub6_1" />
		<axis xyz="-0.866025 0.5 0"/>
		<limit lower="-1e+16" upper="1e+16" effort="1.5" velocity="50" />
		<joint_properties friction="0.0"/>
	</joint>
	<link name="wheel2_sub11_1">
		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
		<inertial>
			<origin xyz="3.67355e-05 -2.09868e-05 5.31199e-07" rpy="0 0 0"/>
			<mass value="9.9564e-05" />
			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
		</inertial>
	</link>
	<joint name="wheel2_sub12" type="revolute">
		<origin xyz="-3.05311e-16 0.0165 0.0102056" rpy="3.13965 -0.00112434 2.61799" />
		<parent link="horn4_1" />
		<child link="wheel2_sub11_1" />
		<axis xyz="-0.866025 0.5 0"/>
		<limit lower="-1e+16" upper="1e+16" effort="1.5" velocity="50" />
		<joint_properties friction="0.0"/>
	</joint>
	<joint name="wheel4" type="revolute">
		<origin xyz="0.0595475 -0.0498349 -0.138971" rpy="1.5708 1.43948 1.08609" />
		<parent link="body_1" />
		<child link="horn4_1" />
		<axis xyz="0 0 -1"/>
		<limit lower="-1e+16" upper="1e+16" effort="1.5" velocity="100" />
		<joint_properties friction="0.0"/>
	</joint>
	<link name="horn2_1">
		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
		<inertial>
			<origin xyz="-1.11491e-06 -2.12888e-08 0.012158" rpy="0 0 0"/>
			<mass value="0.00125567" />
			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
		</inertial>
	</link>
	<link name="wheel3_sub6_1">
		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
		<inertial>
			<origin xyz="3.67355e-05 -2.09868e-05 5.31199e-07" rpy="0 0 0"/>
			<mass value="9.9564e-05" />
			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
		</inertial>
	</link>
	<joint name="wheel3_sub1" type="revolute">
		<origin xyz="0.0142894 0.00825 0.0189056" rpy="2.1658 -0.445999 1.81033" />
		<parent link="horn2_1" />
		<child link="wheel3_sub6_1" />
		<axis xyz="-0.866025 0.5 0"/>
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

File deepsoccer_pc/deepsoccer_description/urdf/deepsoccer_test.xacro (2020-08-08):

<?xml version="1.0"?>
<robot name="jetbot_soccer" xmlns:xacro="http://www.ros.org/wiki/xacro">
	<xacro:include filename="$(find jetbot_description)/urdf/jetbot_soccer_test.gazebo" />

	<link name="body_1">
		<inertial>
			<origin xyz="0 0 0" rpy="0 0 0"/>
			<mass value="1e-9" />
			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
		</inertial>
	</link>

	<link name="body_1_12_part_1">
		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
		<inertial>
			<origin xyz="0 0 0" rpy="0 0 0"/>
			<mass value="0"/>
			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
		</inertial>
	</link>
	<joint name="body_1_body_1_12_part_1_fixing" type="fixed">
		<origin xyz="-0.280051 -0.342952 -0.0926791" rpy="6.97139e-08 8.32148e-08 0.0251544" />
		<parent link="body_1" />
		<child link="body_1_12_part_1" />
		<axis xyz="0 0 0"/>
	</joint>

	<link name="body_1_13_m3_l35mm">
		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
		<inertial>
			<origin xyz="0.17 -3.57955e-11 -0.0175" rpy="0 0 0"/>
			<mass value="0.000921555"/>
			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
		</inertial>
	</link>
	<joint name="body_1_body_1_13_m3_l35mm_fixing" type="fixed">
		<origin xyz="-0.0927726 -0.415205 -0.118531" rpy="3.14159 -1.06701e-07 2.65463" />
		<parent link="body_1" />
		<child link="body_1_13_m3_l35mm" />
		<axis xyz="0 0 0"/>
	</joint>
	<link name="body_1_14_m3_l35mm">
		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
		<inertial>
			<origin xyz="0.17 -3.57955e-11 -0.0175" rpy="0 0 0"/>
			<mass value="0.000921555"/>
			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
		</inertial>
	</link>
	<joint name="body_1_body_1_14_m3_l35mm_fixing" type="fixed">
		<origin xyz="-0.172405 -0.288254 -0.118531" rpy="3.14159 -1.06701e-07 2.65463" />
		<parent link="body_1" />
		<child link="body_1_14_m3_l35mm" />
		<axis xyz="0 0 0"/>
	</joint>
	<link name="body_1_17_m3_l30mm">
		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
		<inertial>
			<origin xyz="0.16 -6.55175e-11 -0.015" rpy="0 0 0"/>
			<mass value="0.000771083"/>
			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
		</inertial>
	</link>
	<joint name="body_1_body_1_17_m3_l30mm_fixing" type="fixed">
		<origin xyz="-0.256915 -0.04564 -0.0812344" rpy="3.14159 7.1782e-08 -1.52052" />
		<parent link="body_1" />
		<child link="body_1_17_m3_l30mm" />
		<axis xyz="0 0 0"/>
	</joint>
	<link name="body_1_18_m3_l30mm">
		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
		<inertial>
			<origin xyz="0.16 -6.55175e-11 -0.015" rpy="0 0 0"/>
			<mass value="0.000771083"/>
			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
		</inertial>
	</link>
	<joint name="body_1_body_1_18_m3_l30mm_fixing" type="fixed">
		<origin xyz="-0.33177 -0.0489804 -0.0812344" rpy="3.14159 7.1782e-08 -1.52052" />
		<parent link="body_1" />
		<child link="body_1_18_m3_l30mm" />
		<axis xyz="0 0 0"/>
	</joint>
	<link name="body_1_23_m3_l35mm">
		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
		<inertial>
			<origin xyz="0.17 -3.57955e-11 -0.0175" rpy="0 0 0"/>
			<mass value="0.000921555"/>
			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
		</inertial>
	</link>
	<joint name="body_1_body_1_23_m3_l35mm_fixing" type="fixed">
		<origin xyz="-0.0577093 -0.348986 -0.118531" rpy="3.14159 -1.06701e-07 2.65463" />
		<parent link="body_1" />
		<child link="body_1_23_m3_l35mm" />
		<axis xyz="0 0 0"/>
	</joint>
	<link name="body_1_26_m3_l30mm">
		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
		<inertial>
			<origin xyz="0.16 -6.55175e-11 -0.015" rpy="0 0 0"/>
			<mass value="0.000771083"/>
			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
		</inertial>
	</link>
	<joint name="body_1_body_1_26_m3_l30mm_fixing" type="fixed">
		<origin xyz="-0.216594 -0.108797 -0.0812344" rpy="3.14159 7.1782e-08 -1.52052" />
		<parent link="body_1" />
		<child link="body_1_26_m3_l30mm" />
		<axis xyz="0 0 0"/>
	</joint>
	<link name="body_1_31_m3_l30mm">
		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
		<inertial>
			<origin xyz="0.16 -6.55175e-11 -0.015" rpy="0 0 0"/>
			<mass value="0.000771083"/>
			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
		</inertial>
	</link>
	<joint name="body_1_body_1_31_m3_l30mm_fixing" type="fixed">
		<origin xyz="-0.353611 -0.182458 -0.0812344" rpy="3.14159 8.48329e-08 -1.34599" />
		<parent link="body_1" />
		<child link="body_1_31_m3_l30mm" />
		<axis xyz="0 0 0"/>
	</joint>
	<link name="body_1_43_m3_l35mm">
		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
		<inertial>
			<origin xyz="0.17 -3.57955e-11 -0.0175" rpy="0 0 0"/>
			<mass value="0.000921555"/>
			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
		</inertial>
	</link>
	<joint name="body_1_body_1_43_m3_l35mm_fixing" type="fixed">
		<origin xyz="-0.207469 -0.354474 -0.118531" rpy="3.14159 -1.06701e-07 2.65463" />
		<parent link="body_1" />
		<child link="body_1_43_m3_l35mm" />
		<axis xyz="0 0 0"/>
	</joint>
	<link name="body_1_51_m3_l30mm">
		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
		<inertial>
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

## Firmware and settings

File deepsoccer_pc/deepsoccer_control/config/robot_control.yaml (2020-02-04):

# Publish all joint states -----------------------------------
joint_state_controller:
  type: joint_state_controller/JointStateController
  publish_rate: 50  
  
# Position Controllers ---------------------------------------
joint1_velocity_controller:
  type: velocity_controllers/JointVelocityController
  joint: wheel1
  pid: {p: 100.0, i: 0.01, d: 10.0}
joint2_velocity_controller:
  type: velocity_controllers/JointVelocityController
  joint: wheel2
  pid: {p: 100.0, i: 0.01, d: 10.0}
joint3_velocity_controller:
  type: velocity_controllers/JointVelocityController
  joint: wheel3
  pid: {p: 100.0, i: 0.01, d: 10.0}
joint3_velocity_controller:
  type: velocity_controllers/JointVelocityController
  joint: wheel4
  pid: {p: 100.0, i: 0.01, d: 10.0}

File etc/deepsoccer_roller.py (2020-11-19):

#!/usr/bin/env python
import rospy
import time

import RPi.GPIO as GPIO
from std_msgs.msg import String


# sets motor speed between [-1.0, 1.0]
def set_speed(motor_ID, value):
    max_pwm = 115.0
    speed = int(min(max(abs(value * max_pwm), 0), max_pwm))
    if value > 0:
        GPIO.output(5, GPIO.HIGH)
        GPIO.output(6, GPIO.LOW)
    else:
        GPIO.output(5, GPIO.LOW)
        GPIO.output(6, GPIO.HIGH)


# stops all motors
def all_stop():
    GPIO.output(5, GPIO.HIGH)
    GPIO.output(6, GPIO.HIGH)
    

# directional commands (degree, speed)
def on_cmd_dir(msg):
    rospy.loginfo(rospy.get_caller_id() + ' cmd_dir=%s', msg.data)

    
# raw L/R motor commands (speed, speed)
def on_cmd_raw(msg):
    rospy.loginfo(rospy.get_caller_id() + ' cmd_raw=%s', msg.data)

    
# simple string commands (left/right/forward/backward/stop)
def on_cmd_str(msg):
    rospy.loginfo(rospy.get_caller_id() + ' cmd_str=%s', msg.data)

    if msg.data.lower() == "in":
        #set_speed(motor_ID,   1.0)
        GPIO.output(5, GPIO.HIGH)
        GPIO.output(6, GPIO.LOW)
    elif msg.data.lower() == "out":
        GPIO.output(5, GPIO.LOW)
        GPIO.output(6, GPIO.HIGH)
        #set_speed(motor_ID,  -1.0) 
    elif msg.data.lower() == "stop":
        all_stop()
    else:
        rospy.logerror(rospy.get_caller_id() + ' invalid cmd_str=%s', msg.data)


# initialization
if __name__ == '__main__':
    GPIO.setmode(GPIO.BCM)  # BCM pin-numbering scheme from Raspberry Pi
    
    # setup motor gpio
    GPIO.setup(5, GPIO.OUT, initial=GPIO.HIGH)
    GPIO.setup(6, GPIO.OUT, initial=GPIO.HIGH)

    # stop the motors as precaution
    all_stop()

    # setup ros node
    rospy.init_node('deepsoccer_roller')
    
    rospy.Subscriber('~cmd_dir', String, on_cmd_dir)
    rospy.Subscriber('~cmd_raw', String, on_cmd_raw)
    rospy.Subscriber('~cmd_str', String, on_cmd_str)

    # start running
    rospy.spin()

    # stop motors before exiting
    all_stop()

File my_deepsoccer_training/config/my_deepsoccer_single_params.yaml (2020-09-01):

deepsoccer: #namespace
    task_and_robot_environment_name: 'MyDeepSoccerSingle-v0'
    ros_ws_abspath: "/home/kimbring2/catkin_ws"
    running_step: 0.04 # amount of time the control will be executed
    pos_step: 0.016     # increment in position for each command
    
    #qlearn parameters
    alpha: 0.1
    gamma: 0.7
    epsilon: 0.9
    epsilon_discount: 0.999
    nepisodes: 500
    nsteps: 10000
    running_step: 0.06 # Time for each step

    save_path: "/home/kimbring2/catkin_ws/src/my_deepsoccer_training/human_data/"
    save_file: "jetbot_soccer_data_0"

deepsoccer_test: #namespace
    task_and_robot_environment_name: 'MyDeepSoccerSingleTest-v0'
    ros_ws_abspath: "/home/kimbring2/catkin_ws"
    running_step: 0.04 # amount of time the control will be executed
    pos_step: 0.016     # increment in position for each command
    
    #qlearn parameters
    alpha: 0.1
    gamma: 0.7
    epsilon: 0.9
    epsilon_discount: 0.999
    nepisodes: 500
    nsteps: 10000
    running_step: 0.06 # Time for each step

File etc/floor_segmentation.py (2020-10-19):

# MIT License
# Copyright (c) 2019 JetsonHacks
# See license
# Using a CSI camera (such as the Raspberry Pi Version 2) connected to a
# NVIDIA Jetson Nano Developer Kit using OpenCV
# Drivers for the camera and OpenCV are included in the bEase image

import cv2
import numpy as np
import tensorflow as tf

def create_mask(pred_mask):
  pred_mask = tf.argmax(pred_mask, axis=-1)
  pred_mask = pred_mask[..., tf.newaxis]
  return pred_mask[0]

# gstreamer_pipeline returns a GStreamer pipeline for capturing from the CSI camera
# Defaults to 1280x720 @ 60fps
# Flip the image by setting the flip_method (most common values: 0 and 2)
# display_width and display_height determine the size of the window on the screen

imported_seg = tf.saved_model.load("/home/kimbring2/segmentation_model_official/")
f_seg = imported_seg.signatures["serving_default"]
seg_test_input = np.zeros([1,256,256,3])
seg_test_tensor = tf.convert_to_tensor(seg_test_input, dtype=tf.float32)
print(f_seg(seg_test_tensor))

#imported_style = tf.saved_model.load("/home/kimbring2/Desktop/style_model")
#f_style = imported_style.signatures["serving_default"]
#style_test_input = np.zeros([1,256,256,3])
#style_test_tensor = tf.convert_to_tensor(style_test_input, dtype=tf.float32)
#f_style(style_test_tensor)['output_1']

path_raw_video = '/home/kimbring2/Desktop/raw_video.avi'
path_dilation_video = '/home/kimbring2/Desktop/dilation_video.avi'
path_blue_video = '/home/kimbring2/Desktop/blue_video.avi'
path_green_video = '/home/kimbring2/Desktop/green_video.avi'
path_segmented_video = '/home/kimbring2/Desktop/segmented_video.avi'

fps = 5
raw_video_out = cv2.VideoWriter(path_raw_video, cv2.VideoWriter_fourcc(*'DIVX'), fps, (1280,720))
dilation_video_out = cv2.VideoWriter(path_dilation_video, cv2.VideoWriter_fourcc(*'DIVX'), fps, (1280,720))
blue_video_out = cv2.VideoWriter(path_blue_video, cv2.VideoWriter_fourcc(*'DIVX'), fps, (1280,720))
green_video_out = cv2.VideoWriter(path_green_video, cv2.VideoWriter_fourcc(*'DIVX'), fps, (1280,720))
segmented_video_out = cv2.VideoWriter(path_segmented_video, cv2.VideoWriter_fourcc(*'DIVX'), fps, (1280,720))

def gstreamer_pipeline(
    capture_width=1280,
    capture_height=720,
    display_width=1280,
    display_height=720,
    framerate=20,
    flip_method=0,
):
    return (
        "nvarguscamerasrc ! "
        "video/x-raw(memory:NVMM), "
        "width=(int)%d, height=(int)%d, "
        "format=(string)NV12, framerate=(fraction)%d/1 ! "
        "nvvidconv flip-method=%d ! "
        "video/x-raw, width=(int)%d, height=(int)%d, format=(string)BGRx ! "
        "videoconvert ! "
        "video/x-raw, format=(string)BGR ! appsink"
        % (
            capture_width,
            capture_height,
            framerate,
            flip_method,
            display_width,
            display_height,
        )
    )


def show_camera():
    # To flip the image, modify the flip_method parameter (0 and 2 are the most common)
    #print(gstreamer_pipeline(flip_method=0))
    cap = cv2.VideoCapture(gstreamer_pipeline(flip_method=0), cv2.CAP_GSTREAMER)
    if cap.isOpened():
        #window_handle = cv2.namedWindow("CSI Camera", cv2.WINDOW_AUTOSIZE)
        # Window
        #while cv2.getWindowProperty("CSI Camera", 0) >= 0:
        while True:
            print("True")
                
            ret, frame = cap.read()
            frame = cv2.rotate(frame, cv2.ROTATE_180)
            raw_video_out.write(frame)
            img_ = cv2.resize(frame, (256, 256), interpolation=cv2.INTER_AREA)
            #cv2.imwrite("original_image.jpg", img_)
            
            img_ = cv2.normalize(img_, None, 0, 1, cv2.NORM_MINMAX, cv2.CV_32F)
            #cv_image = cv2.cvtColor(cv_image, cv2.COLOR_RGB2RGBA).astype(np.float32)
            
            resized = np.array([img_])
            input_tensor = tf.convert_to_tensor(resized, dtype=tf.float32)
            output = f_seg(input_tensor)['conv2d_transpose_4'].numpy()
            #output_style = f_style(input_tensor)['output_1'].numpy()[0]
            #print("output_style.shape: " + str(output_style.shape))
            #cv2.imwrite("output_style.jpg", output_style)
            
            pred_mask = tf.keras.preprocessing.image.array_to_img(create_mask(output))
            pred_mask = np.array(pred_mask)
            #print("pred_mask.shape: " + str(pred_mask.shape))
            #print("pred_mask: " + str(pred_mask))
            ret, thresh = cv2.threshold(pred_mask, 126, 255, cv2.THRESH_BINARY)
            
            kernel = np.ones((5, 5), np.uint8)
            erodition_image = cv2.erode(thresh, kernel, iterations=2)  #// make dilation image
            dilation_image = cv2.dilate(erodition_image, kernel, iterations=2)  #// make dilation image
            dilation_image = cv2.resize(dilation_image, dsize=(1280,720), interpolation=cv2.INTER_AREA)
            dilation_image = np.float32(dilation_image)
            #dilation_image = cv2.resize(np.float32(dilation_image), dsize=(1280,720), interpolation=cv2.INTER_AREA)
            dilation_image_rgb = cv2.cvtColor(dilation_image, cv2.COLOR_GRAY2RGB)
            print("np.uint8(dilation_image_rgb).shape: " + str(np.uint8(dilation_image_rgb).shape))
            dilation_video_out.write(np.uint8(dilation_image_rgb))
            dilation_image = dilation_image != 255.0
            
            # converting from BGR to HSV color space
            hsv_frame = cv2.cvtColor(frame, cv2.COLOR_BGR2HSV)

            # Red color
            low_red = np.array([120, 155, 84])
            high_red = np.array([179, 255, 255])
            red_mask = cv2.inRange(hsv_frame, low_red, high_red)
            red = cv2.bitwise_and(frame, frame, mask=red_mask)

            # Blue color
            low_blue = np.array([110, 130, 2])
            high_blue = np.array([126, 255, 255])
            blue_mask = cv2.inRange(hsv_frame, low_blue, high_blue)
            kernel = np.ones((10, 10), np.uint8)
            blue_mask = cv2.dilate(blue_mask, kernel, iterations=1)  #// make dilation image
            blue = cv2.bitwise_and(frame, frame, mask=blue_mask)
            #cv2.imwrite("blue.jpg", blue)
            blue_video_out.write(blue)

            # Green color
            low_green = np.array([25, 52, 72])
            high_green = np.array([60, 255, 255])
            green_mask = cv2.inRange(hsv_frame, low_green, high_green)
            kernel = np.ones((5, 5), np.uint8)
            green_mask = cv2.dilate(green_mask, kernel, iterations=1)  #// make dilation image
            green = cv2.bitwise_and(frame, frame, mask=green_mask)
            #cv2.imwrite("green.jpg", green)
            green_video_out.write(green)

            mask = dilation_image - green_mask - blue_mask
            #mask = green_mask + dilation_image

            result = cv2.bitwise_and(frame, frame, mask=mask)
            #cv2.imwrite("segmented_image.jpg", result)
            
            result_mean = np.mean(result)
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

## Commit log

2019-10-25 Add files via upload
    Initial update
    [JetBot-v3-Wheel.stl, jetbot.urdf, jetbot.xacro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]
2019-10-29 Add files via upload
    Soccer related model file upload
    [model.sdf]
2019-11-01 Add files via upload
    Find stable model parameter
    [jetbot.xacro]
2019-12-05 Add files via upload
    Phisical Parameter Update
    [jetbot.xacro]
2019-12-06 Add files via upload
    Transmission is changed from effort to velocity
    [jetbot.xacro]
2019-12-09 Add files via upload
    Ball size change
    [model.sdf]
2019-12-09 Add files via upload
    Field size change
    [model.sdf]
2019-12-29 Add files via upload
    Solenoid motor update
2019-12-29 Update README.md
    Solenoid, roller uppdate
2020-01-17 Add files via upload
    Jetbot prototype version 1 update
2020-01-19 Add files via upload
    Jetbot soccer urdf file update
    [1.14_tft_ips_-_13p_-_reverse_mount.step.stl, 12v.step.stl, ____.step.stl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]
2020-01-30 Add files via upload
    Add xacro file for only RViz
    [jetbot_rviz.xacro]
2020-02-02 Add files via upload
    Jetbot soccer model update
    [1.14_tft_ips_-_13p_-_reverse_mount.step.stl, 12v.step.stl, ____.step.stl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]
2020-02-03 Add files via upload
    Change a controller from effort_controllers to velocity_controllers
2020-02-04 Add files via upload
    Jetbot soccer version config file update
    [robot_control.yaml]
2020-02-04 change urdf folder name
    [1.14_tft_ips_-_13p_-_reverse_mount.step.stl, 12v.step.stl, ____.step.stl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]
2020-02-04 change file and folder name
    [jetbot_soccer.urdf, jetbot_soccer.xacro, jetbot_soccer_rviz.xacro]
2020-02-26 Control by ROS topic update
    [jetbot_soccer.xacro, jetbot_soccer_rviz.xacro, jetbot_soccer_test.xacro]
2020-03-01 Add files via upload
    Could not find the GUI, install the 'joint_state_publisher_gui' package update
2020-03-01 Update README.md
    joint_state_publisher_gui issue solve method update
2020-03-03 stick update
    [4pin_smd.stl, c6aaa.stl, camera_holder.stl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]
2020-03-06 dribble update
    [body_1.stl, body_2.stl, jetbot_soccer.xacro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]
2020-03-12 Update README.md
    Jetbot soccer solenoid and roller ROS code update
2020-03-12 motor ros script update
2020-03-12 Update README.md
    Motor control ros script update
2020-03-20 omniwheel subwheel update
    [____.step.stl, jetbot_soccer.xacro, jetbot_soccer_rviz.xacro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]
2020-03-20 omniwheel subwheel update new
    [jetbot_soccer.xacro, model.sdf]
2020-05-21 lidar sensor, model update
    [____.step.stl, adesivo.stl, body_1.stl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]
2020-07-08 Add files via upload
    Second prototype update
2020-07-16 Add files via upload
    Lidar sensor bug fix
2020-07-19 Update README.md
    Lidar sensor update
2020-07-28 Add files via upload
    Solenoid controller update
2020-07-29 Add files via upload
    ROS lidar python script upload
2020-07-29 solenoid plugin update
    [jetbot.xacro, jetbot_rviz.xacro, jetbot_soccer.xacro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]
2020-07-29 Add files via upload
    Spring physics image update
2020-08-02 Add files via upload
    Steering unbalance problem solve
    [jetbot_soccer.xacro]
2020-08-08 inertia update
    [jetbot_soccer_rviz.xacro, jetbot_soccer_test.xacro, model.sdf]
2020-08-16 solenoid kicker update
    [jetbot_soccer.xacro, model.sdf]
2020-08-18 Update README.md
    Update text for Solenoid Electromagnet
2020-08-27 infrared sensor add
    [antenna_1.stl, antenna_2.stl, body_2.stl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]
2020-08-27 Add files via upload
    Infrared sensor script for real robot update
2020-08-29 Add files via upload
    Camera link update
2020-09-01 ForgER update
    [jetbot_soccer.xacro]
2020-09-01 torsional spring plugin folder delete
2020-09-05 Update README.md
    Wheel command for real deepsoccer update
2020-09-05 Original jetbot file delete
    [JetBot-v3-Wheel.stl, jetbot.urdf, jetbot.xacro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]
2020-09-10 missing file update
    [JetBot-v3-Wheel.stl, model.sdf]
2020-09-10 Add files via upload
    cv_bridge for Python 3, Solenoid command update
2020-09-11 Update README.md
    Pretrained model usage at Jetson Nano update
2020-09-17 Add files via upload
    Solenoid traitlets update
2020-09-17 Add files via upload
    Jetbot package '/usr/local/lib/python3.6/dist-packages/jetbot-0.4.0-py3.6.egg/jetbot/camera/opencv_gst_camera.py' file update for video recording
2020-10-16 package name change
    [1.14_tft_ips_-_13p_-_reverse_mount.step.stl, 12v.step.stl, 4pin_smd.stl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]
2020-10-19 Update README.md
    Segmentation sample code and model update
2020-10-19 Jetson Nano ROS package name change
    [1.14_tft_ips_-_13p_-_reverse_mount.step.stl, 12v.step.stl, 4pin_smd.stl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]
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2020-10-19 Update README.md
    Jetson Nano ROS package name changing
2020-11-19 Add files via upload
    Jetson Xavier NX circuit picture update
2020-11-19 Add files via upload
    DC motor driver change
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2021-03-11 clean up
    [1.14_tft_ips_-_13p_-_reverse_mount.step.stl, 12v.step.stl, 4pin_smd.stl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]
2021-07-13 Add files via upload
    Friction paramter update
    [model.sdf]
2021-07-13 Add files via upload
    Friction parameter update
    [model.sdf]
2021-07-13 Add files via upload
    Roller speed limit, friction parameter update
    [deepsoccer_1.xacro]
2021-09-08 Add files via upload
    RGB to BGR update for camera input
2021-09-10 Add files via upload
    Path update
    [model.sdf]
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
